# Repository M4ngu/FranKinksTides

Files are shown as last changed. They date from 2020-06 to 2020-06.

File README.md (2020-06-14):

# FranKinksTides
cc-by-sa original     design by Émile Gillet

https://www.tesseractmodular.com/eurorack-modules/frankinkstides-1-2

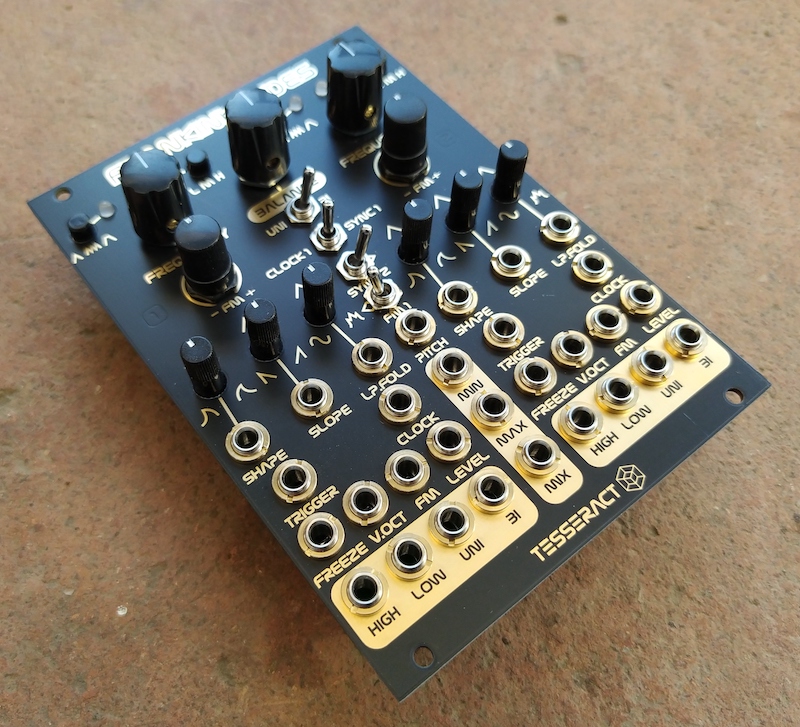
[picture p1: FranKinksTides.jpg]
FranKinksTides


Dual Tidal Modulator - Eurorack Module

FranKinksTides is a eurorack module with 2 tidal modulators based on MI Tides1 (by Émilie Gillet) and the Swirls PCB layout  (by Electric Mist)

https://mutable-instruments.net/modules/tides1/

The central part is a mixer for the 2 signals and the Max/Min circuit from MI Kinks 

https://mutable-instruments.net/modules/kinks/

It can be a dual function generator, a complex oscillator or any other combination of VCO, LFO, ENV

version history:

## first version

-First working version of this kind of 'digital Maths'

## second version (v1.2):

-Mix output is now buffered, no signal bleeding on single outs.

-Mix pot controls also the balance of the signals sent to the max/min circuit.

-Uni/bi switch now also determines the signal sent to FM1.

-Clock/sync switch has now a center OFF position, no need of plugging a dummy cable in the Clock1 when using Sheeps firmware to avoid ultra fast sound bank changes. 

other small improvements for DIY:

-Bigger font size on the pcb.

-Parts renumbered for easy DIY.

## last version (v1.4):

-Added resistors to make the Balance pot exponential, so center position has a louder output.

-PCB modified with the Thonkiccon recommendation (with no ground plane / traces under the jacks)

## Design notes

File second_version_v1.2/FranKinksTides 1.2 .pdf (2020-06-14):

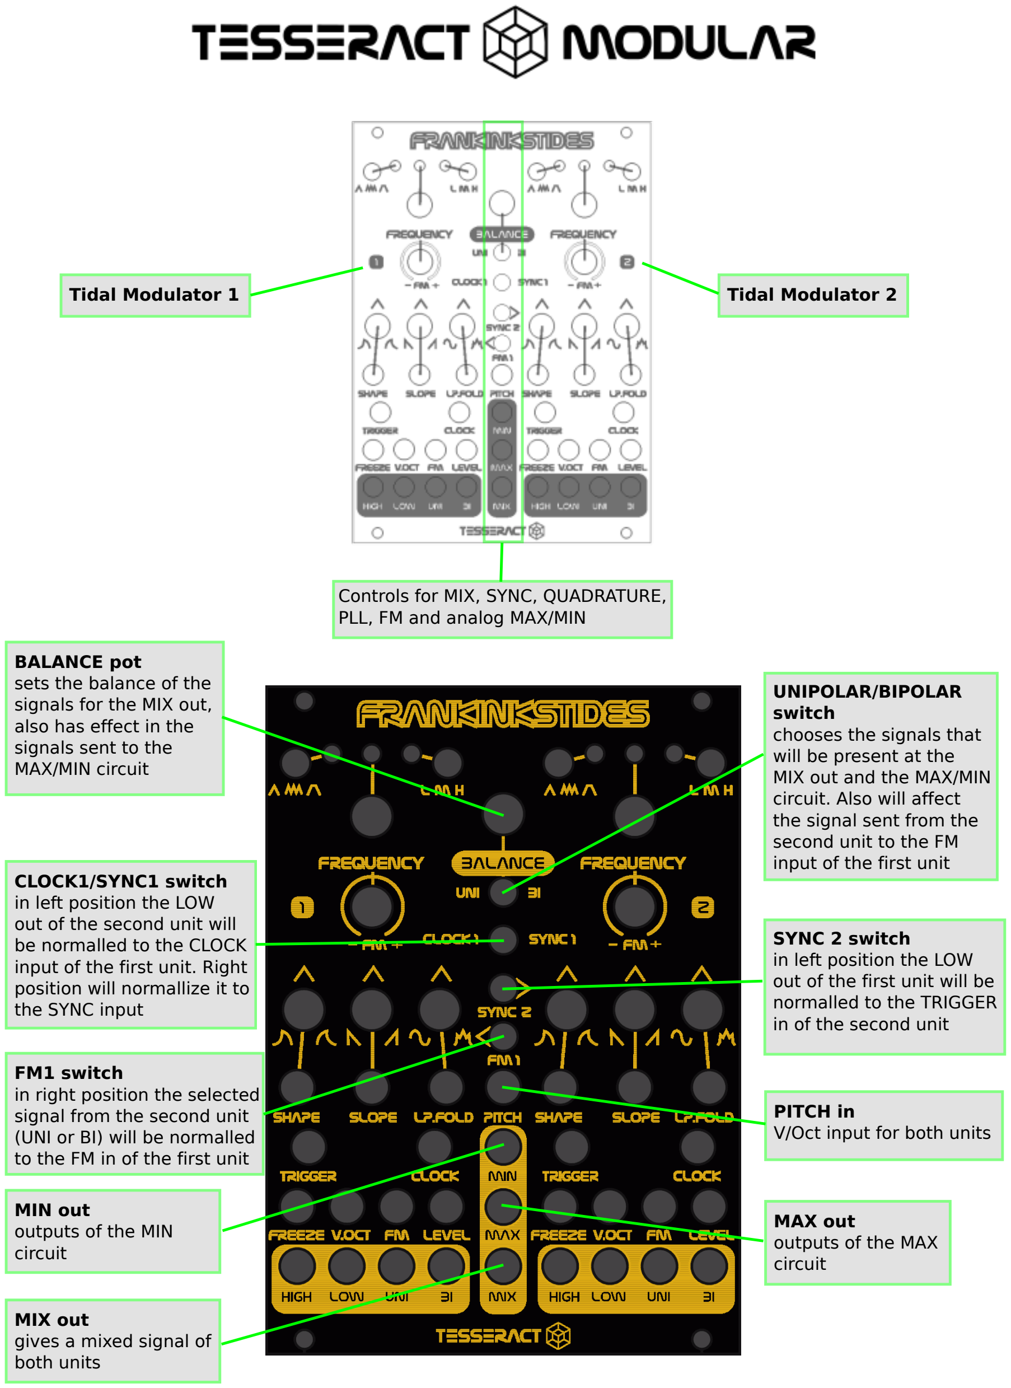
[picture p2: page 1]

BALANCE pot
sets the balance of the
signals for the MIX out,
also has effect in the
signals sent to the
MAX/MIN circuit

UNIPOLAR/BIPOLAR
switch
chooses the signals that
will be present at the
MIX out and the MAX/MIN
circuit. Also will affect
the signal sent from the
second unit to the FM
input of the first unit

MIX out
gives a mixed signal of
both units

MIN out
outputs of the MIN
circuit

SYNC 2 switch
in left position the LOW
out of the first unit will be normalled to the TRIGGER
in of the second unit

CLOCK1/SYNC1 switch
in left position the LOW
out of the second unit will be normalled to the CLOCK
input of the first unit. Right position will normallize it to the SYNC input

MAX out
outputs of the MAX
circuit

PITCH in
V/Oct input for both units

FM1 switch
in right position the selected signal from the second unit (UNI or BI) will be normalled to the FM in of the first unit
Tidal Modulator 1 | Tidal Modulator 2

Controls for MIX, SYNC, QUADRATURE, PLL, FM and analog MAX/MIN

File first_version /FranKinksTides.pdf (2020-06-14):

# FranKinksTides – Tesseract Modular

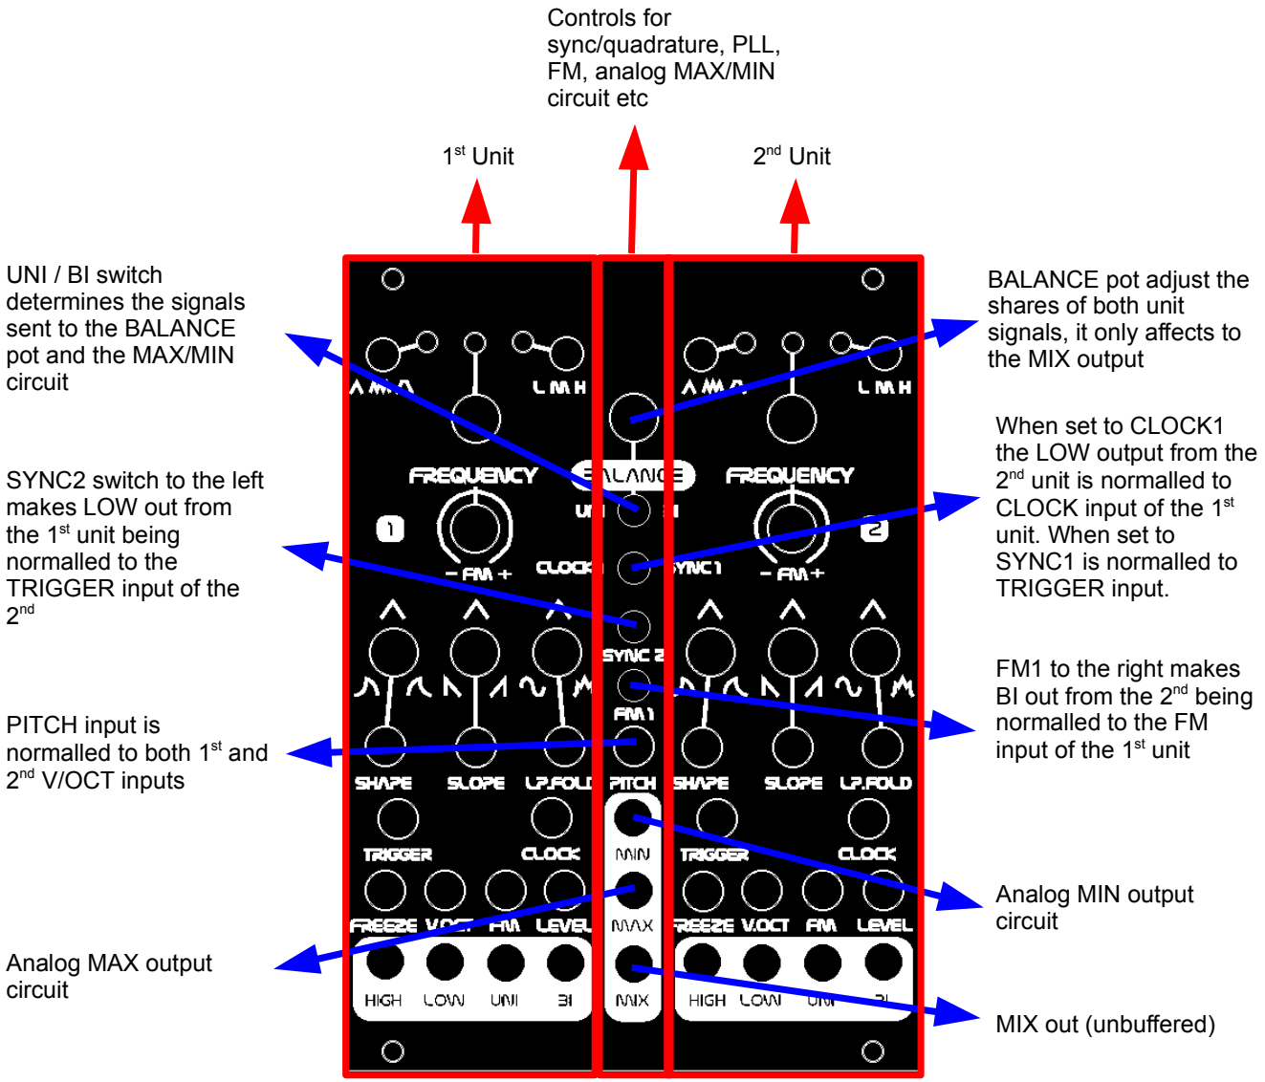
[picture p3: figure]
BALANCE pot adjust the shares of both unit signals, it only affects to the MIX output; UNI / BI switch determines the signals sent to the BALANCE pot and the MAX/MIN circuit; SYNC2 switch to the left makes LOW out from the 1st unit being normalled to the TRIGGER input of the 2; PITCH input is normalled to both 1st and 2; nd V/OCT inputs; FM1 to the right makes BI out from the 2nd being normalled to the FM input of the 1st unit; When set to CLOCK1 the LOW output from the 2; nd unit is normalled to CLOCK input of the 1st unit. When set to SYNC1 is normalled to TRIGGER input.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

B.O.M.:
htps://drive.google.com/open?id=1qt1LPLmPkDN1XobC-u9hoLfQJoos-VuX2zH6MlWJix4

MOUSER CART (without pots, switches and jacks): htps://www.mouser.com/ProjectManager/ProjectDetail.aspx?AccessID=BC3FC77538

Derivatve work from MUTABLE INSTRUMENTS TIDES & KINKS by Olivier Gillet Based on the SWIRLS layout by Electric Mist

cc-by-sa

htps://www.facebook.com/Tesseract-Modular-146727136274298

tesseract.modular@gmail.com

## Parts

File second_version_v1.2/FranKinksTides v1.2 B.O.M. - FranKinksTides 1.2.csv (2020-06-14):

Index | Value | Qty | Description | Specs | Package | Ref. Mouser | References
R120 | 51 | 1 | Resistor, 1% |  | 603 | 603-RC0603FR-0751RL
R3, R4, R5, R6, R7, R8, R9, R10, R11, R12, R13, R14, R71, R74, R94, R95 | 100 | 16 | Resistor, 1% |  | 603 | 652-CR0603FX-1000ELF
R76, R83 | 180 | 2 | Resistor, 1% |  | 603 | 652-CR0603FX-1800ELF
R66, R67 | 270 | 2 | Resistor, 1% |  | 603 | 652-CR0603FX-2700ELF
R20, R21 | 2.49k | 2 | Resistor, 1% |  | 603 | 652-CR0603FX-2491ELF
R88, R89 | 2.49k | 2 | Resistor, 1% |  | 805 | 652-CR0805FX-2491ELF
R64, R65, R103, R106, R112, R115 | 3.3k | 6 | Resistor, 1% |  | 603 | 652-CR0603-FX3301ELF
R104, R105, R113, R114 | 4.7k | 4 | Resistor, 1% |  | 603 | 652-CR0603FX-4701ELF
R96, R97, R98, R99, R100, R101, R102, R107, R111, R116 | 10k | 10 | Resistor, 1% |  | 603 | 652-CR0603-FX-1002GLF
R52, R53 | 20k | 2 | Resistor, 1% |  | 603 | 652-CR0603FX-2002ELF
R28, R31 | 27k | 2 | Resistor, 1% |  | 603 | 652-CR0603FX-2702ELF
R77, R78 | 30k | 2 | Resistor, 1% |  | 603 | 652-CR0603FX-3002ELF
R39, R41, R42, R43, R44, R45, R84, R85, R86, R87 | 33k | 10 | Resistor, 1% |  | 603 | 652-CR0603FX-3302ELF
R48, R51 | 39k | 2 | Resistor, 1% |  | 603 | 652-CR0603FX-3902ELF
R17, R18, R19, R22, R23, R26, R27, R29, R30, R32, R33, R34, R35, R36, R37, R38, R40, R47, R50, R58, R59, R60, R61, R62, R63, R79, R80, R81, R82, R91, R93, R108, R109, R110, R117, R118, R119 | 100k | 37 | Resistor, 1% |  | 603 | 652-CR0603-FX-1003GLF
R24, R25, | 100k | 2 | Resistor 1% |  | 603 | 652-CR0603-FX-1003GLF | pulldown resistors, other values possible
R54, R55, R56, R57, R70, R73 | 120k | 6 | Resistor, 1% |  | 603 | 652-CR0603FX-1203ELF
R1, R2, R15, R16, R72, R75, R90, R92 | 220k | 8 | Resistor, 1% |  | 603 | 652-CR0603FX-2203ELF
R46, R49 | 3.3M | 2 | Resistor, 1% |  | 603 | 71-CRCW06033M30FKEA
C20 | 10p | 1 | Capacitor, ceramic | >= 16V, <= 5%, C0G | 603 | 81-GCM1885C2A100JA6J
C10, C11, C12, C13 | 18p | 4 | Capacitor, ceramic |  | 603 | 81-GRM185C1H180JA01J
C58, C60, C62, C63, C64, C65, C70, C71 | 220p | 8 | Capacitor, ceramic | >= 16V, <= 2%, C0G | 603 | 81-GRM185C1H221GA01D
C30, C31, C41, C43, C46, C47 | 1n | 6 | Capacitor, ceramic | >= 50V, <= 2%, C0G | 603 | 81-GRM1885C1H102FA1J
C32, C33, C34, C35, C40, C42 | 10n | 6 | Capacitor, ceramic | >= 50V, <= 5% | 603 | 81-GCM188R71H103JA7D
C1, C2, C3, C4, C14, C15, C16, C21, C22, C23, C24, C25, C26, C27, C36, C37, C38, C39, C44, C45, C48, C49, C56, C57, C59, C61, C66, C67, C68, C69 | 100n | 30 | Capacitor, ceramic | >= 16V | 603 | 80-C0603C104K4R7411
C52, C53, C54, C55 | 470n | 4 | Capacitor, ceramic | >= 16V | 603 | 581-0603YG474Z
C28, C29, C50, C51 | 3.3u | 4 | Capacitor, ceramic | >= 6.3V | 603 | 81-GCJ188C70J335KE2D
C6, C7, C8, C9, C17, C18 | 22u | 6 | Capacitor, electrolytic | >= 25V | Panasonic C | 667-EEE-FP1E220AR | EEE-FP1E220AR
C5, C19 | 47u | 2 | Capacitor, electrolytic | >= 25V | Panasonic D | 667-EEE-FK1V470P | EEEFK1V470P
D4, D8 |  | 2 | 1N5819HW diode |  | SOD123 | 621-1N5819HW-F | Diodes Inc 1N5819HW-7-F
D1, D2, D3, D5, D6, D7 |  | 6 | 1N4148 |  | SOD123 | 621-1N4148W-F
IC1, IC2, IC3, IC4 | 3.3V | 4 | LM1117-3.3V LDO Vreg |  | SO223 | 926-LM1117MPX3.3NOPB | National LM1117MPX3.3NOPB
IC11, IC12 | 2.5V | 2 | LM4040 Shunt Vref | A, B or C grade | SOT23 | 595-LM4040C25IDBZR | Texas Instruments LM4040C25IDBZ
IC13, IC14 | 10V | 2 | LM4040 Shunt Vref | A, B or C grade | SOT23 | 595-LM4040C10IDBZR | Texas Instruments LM4040C10IDBZ
IC9, IC10 |  | 2 | DAC8552 dual 16-bit DAC |  | MSOP8 | 595-DAC8552IDGKT | Texas Instruments DAC8552IDGKT
IC15, IC16, IC17, IC18, U1, U2 |  | 6 | TL072 dual op-amp |  | TSSOP-8 | 595-TL072CPWR | TI TL072CPWR
IC7, IC8 |  | 2 | MCP6002 dual op-amp R2R IO |  | SOIC8 | 579-MCP6002-I/SN | MCP6002-I/SN
IC5, IC6 |  | 2 | MCP6004 dual op-amp R2R IO |  | TSSOP-14 | 579-MCP6004-I/ST | MCP6004-I/ST
Q3, Q4, Q5, Q6, Q7, Q8, Q9, Q10, Q11, Q12 |  | 10 | NPN transistor MMBT3904 |  | SOT23 | 863-MMBT3904LT1G | On Semi MMBT3904LT1G
Q1, Q2 |  | 2 | 8 MHz quartz |  | HC49 | 815-ABLS2-8-D4Y-T | Abracon ABLS2-8.000MHZ-D4Y-T
UC1, UC2 |  | 2 | STM32F103CBT6 MCU |  | LQFP48 | 511-STM32F103CBT6 | ST STM32F103CBT6
TH parts
J1, J2, J3, J4, J5, J6, J7, J8, J9, J10, J11, J12, J13, J14, J15, J16, J17, J18, J19, J20, J21, J22, J23, J24, J25, J26, J30, MAX, MIN, MIX |  | 30 | Vertical jack connector |  |  | PJ-301-M-12 | https://www.thonk.co.uk/shop/3-5mm-jacks/
LED1, LED2, LED3, LED4, LED5, LED6 |  | 6 | LED, Red/Green, 3 terminals, common K |  | 3 terminals | 604-WP115VEGW | Kingbright WP115VEGW
SW1, SW2, SW3, SW4 |  | 4 | Push-button 6.0X2.8MM |  |  | 612-TL1105SP-250 | E-switch TL1105SPF250Q
 |  | 4 | Push-button caps |  |  | 612-1R-BK | E-switch 1RBLK
VR1 | 20-100k | 1 | ALPHA-9MM-DUALPOT | linear |  |  | https://www.thonk.co.uk/shop/alpha-9mm-pots-vertical-t18/
R121, R122 |  | 2 | 10k linear pot, 15mm shaft |  |  |  | https://www.thonk.co.uk/shop/alpha-9mm-pots-vertical-t18/
R123, R124, R125, R126, R127, R128, R129, R130 |  | 8 | 10k linear Tall Trimmer |  |  |  | https://www.thonk.co.uk/shop/ttpots/
R68, R69 | 50k | 2 | 50k Trimmer resistor, 25 turns, top adjust. |  |  | 652-3296W-1-503LF | 3296W-1-503LF
POWER |  | 1 | 2x5 male header, 2.54mm pitch |  |  | 649-67996-410HLF
JTAG, JTAG1 |  | 2 | 2x5, 1.27mm pitch male header |  |  | 649-221111-00010T4LF
UNI-BI |  | 1 | Sub-miniature ON-ON | DPDT |  | 108-2MD1T1B1M2QE-EVX | https://www.thonk.co.uk/shop/sub-mini-toggle-switches/
SYNC-A |  | 1 | Sub-miniature ON-OFF-ON | SPDT |  | 108-2MS3T1B1M2QE-EVX
FM-A, SYNC-B |  | 2 | Sub-miniature ON-ON | SPDT |  | 108-2MS1T1B1M2QE-EVX | https://www.thonk.co.uk/shop/sub-mini-toggle-switches/
MOUSER CART (without pots and jacks) | https://www.mouser.com/ProjectManager/ProjectDetail.aspx?AccessID=9fbd7b471f

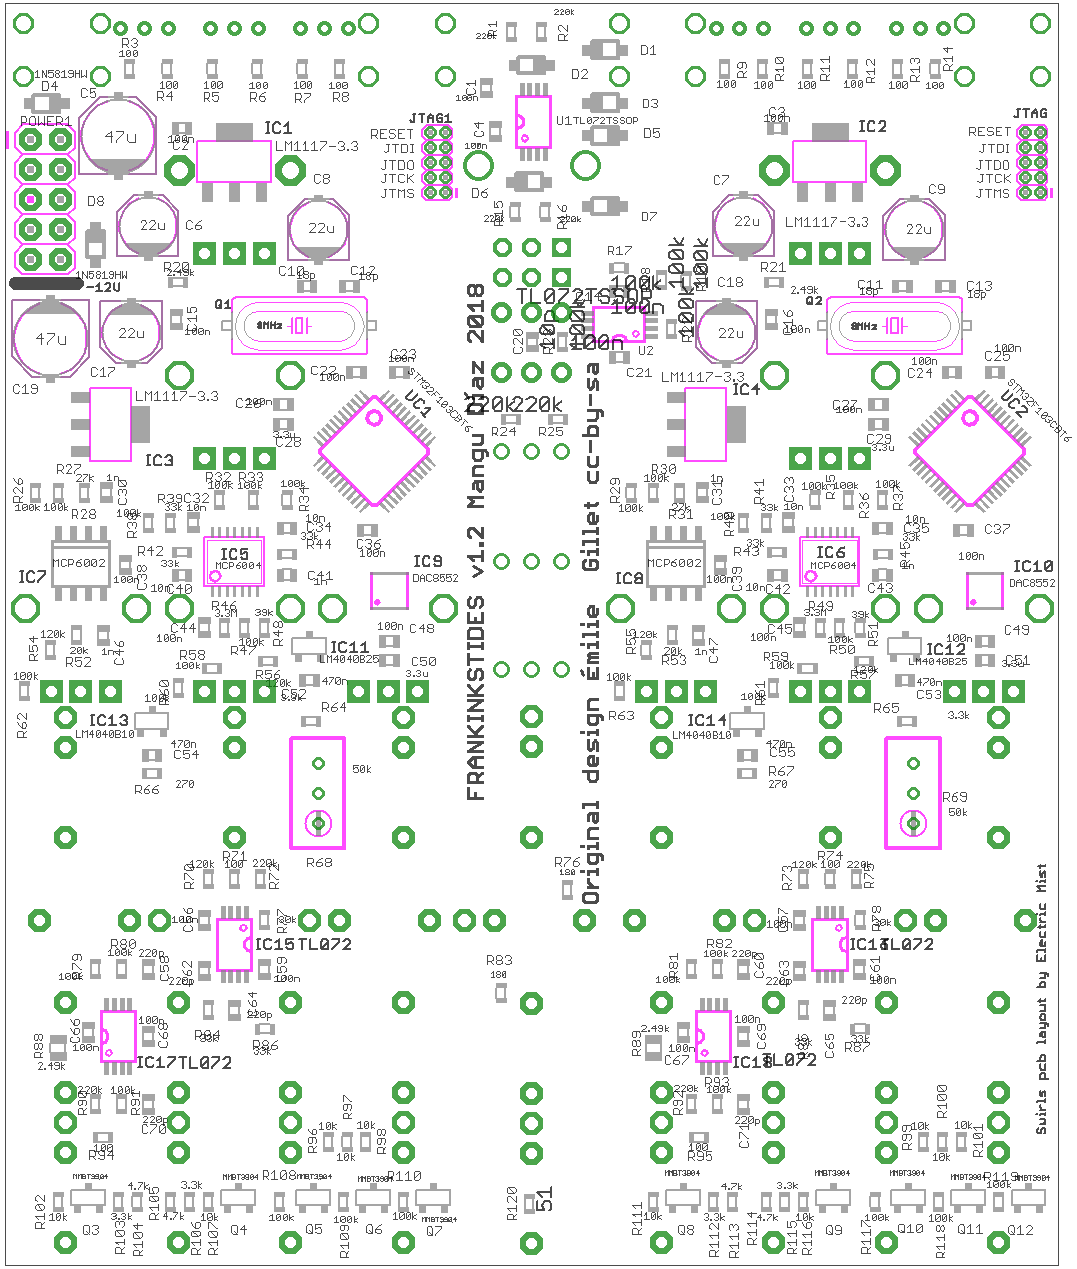
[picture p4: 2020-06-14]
second_version_v1.2/ComponentMap.png

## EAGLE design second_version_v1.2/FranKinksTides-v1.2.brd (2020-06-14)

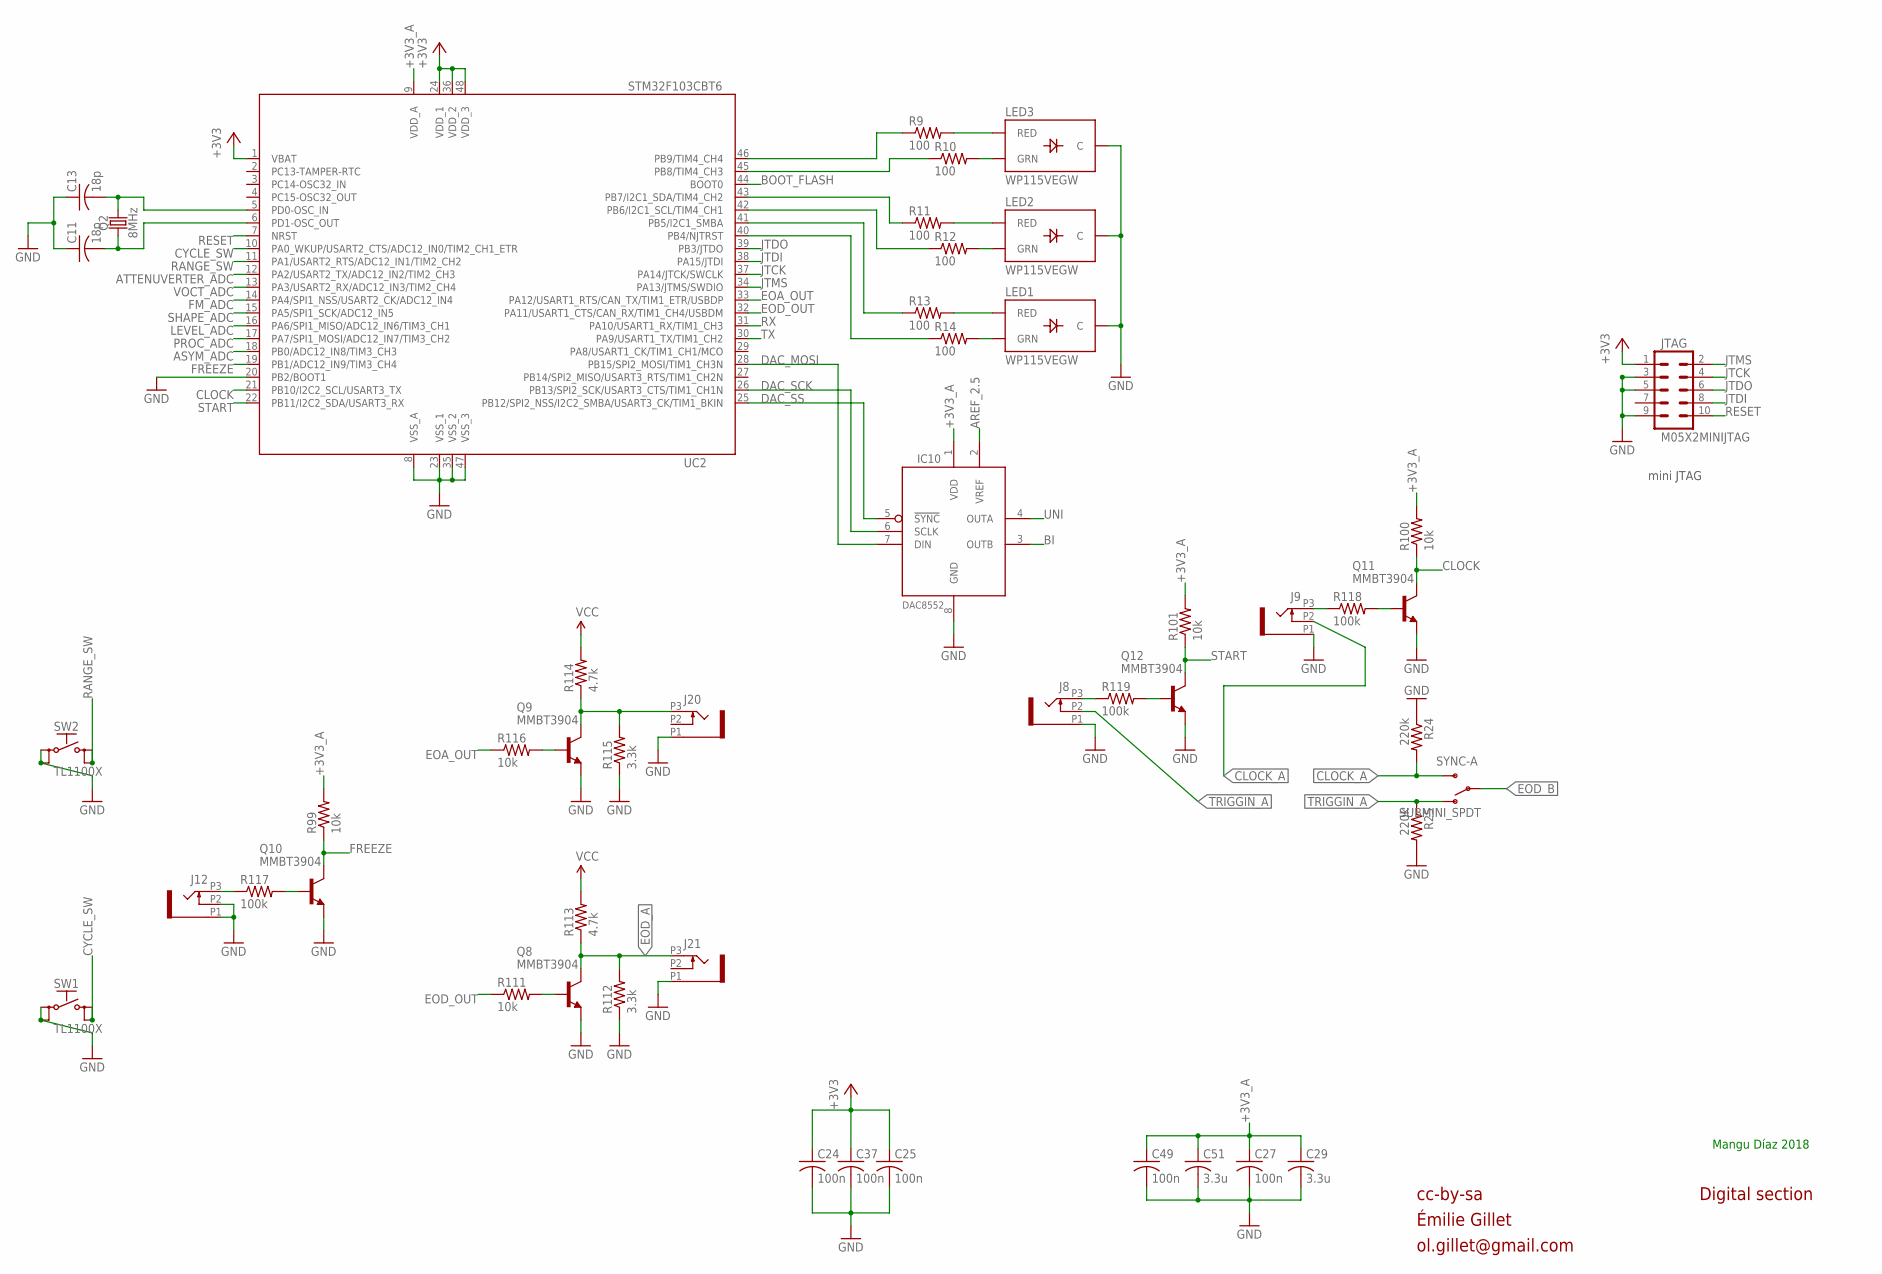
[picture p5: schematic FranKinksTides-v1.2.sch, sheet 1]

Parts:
C11, C13: 18p; C0603
C24, C25, C27, C37, C49: 100n; C0603
C29, C51: 3.3u; C0603
IC10: DAC8552; MSOP-8
J8, J9, J12, J20, J21: PJ301_GUI6; OG-PJ301_VARIATIONS_WQP_PJ_301M6
JTAG: M05X2MINIJTAG; 2X5-1.27
LED1, LED2, LED3: WP115VEGW; LED-BICOLOR-THROUGHHOLE
Q2: 8MHz; HC49UP
Q8, Q9, Q10, Q11, Q12: MMBT3904; SOT23-BEC
R9, R10, R11, R12, R13, R14: 100; R0603
R24, R25: 220k; R0603
R99, R100, R101, R111, R116: 10k; R0603
R112, R115: 3.3k; R0603
R113, R114: 4.7k; R0603
R117, R118, R119: 100k; R0603
SW1, SW2: TL1100X
SYNC-A: SUBMINI_SPDT; SUBMINI_TOGGLE
UC2: STM32F103CBT6; LQFP48

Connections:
+3V3: C24.1, C25.1, C37.1, JTAG.1, UC2.1 (VBAT), UC2.24 (VDD_1), UC2.36 (VDD_2), UC2.48 (VDD_3); also elsewhere on the board
+3V3_A: C27.1, C29.1, C49.1, C51.1, IC10.1 (VDD), R99.2, R100.2, R101.2, UC2.9 (VDD_A); also elsewhere on the board
AREF_2.5: IC10.2 (VREF); also elsewhere on the board
ASYM_ADC: UC2.18 (PB0/ADC12_IN8/TIM3_CH3); also elsewhere on the board
ATTENUVERTER_ADC: UC2.12 (PA2/USART2_TX/ADC12_IN2/TIM2_CH3); also elsewhere on the board
BI: IC10.3 (OUTB); also elsewhere on the board
BOOT_FLASH: UC2.44 (BOOT0); also elsewhere on the board
CLOCK: Q11.C, R100.1, UC2.21 (PB10/I2C2_SCL/USART3_TX); also elsewhere on the board
CLOCK_A: J9.P2 (2), R24.2, SYNC-A.3 (S)
CYCLE_SW: SW1.3 (S), SW1.4 (S1), UC2.10 (PA0_WKUP/USART2_CTS/ADC12_IN0/TIM2_CH1_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); also elsewhere on the board
DAC_MOSI: IC10.7 (DIN), UC2.28 (PB15/SPI2_MOSI/TIM1_CH3N); also elsewhere on the board
DAC_SCK: IC10.6 (SCLK), UC2.26 (PB13/SPI2_SCK/USART3_CTS/TIM1_CH1N); also elsewhere on the board
DAC_SS: IC10.5 (!SYNC), UC2.25 (PB12/SPI2_NSS/I2C2_SMBA/USART3_CK/TIM1_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); also elsewhere on the board
EOA_OUT: R116.1, UC2.33 (PA12/USART1_RTS/CAN_TX/TIM1_ETR/USBDP); also elsewhere on the board
EOD_A: J21.P3 (3), Q8.C, R112.2, R113.1; also elsewhere on the board
EOD_B: SYNC-A.COM (COMMON); also elsewhere on the board
EOD_OUT: R111.1, UC2.32 (PA11/USART1_CTS/CAN_RX/TIM1_CH4/USBDM); also elsewhere on the board
FM_ADC: UC2.14 (PA4/SPI1_NSS/USART2_CK/ADC12_IN4); also elsewhere on the board
FREEZE: Q10.C, R99.1, UC2.19 (PB1/ADC12_IN9/TIM3_CH4); also elsewhere on the board
GND: C11.1, C13.1, C24.2, C25.2, C27.2, C29.2, C37.2, C49.2, C51.2, IC10.8 (GND), J8.P1 (1), J9.P1 (1), J12.P1 (1), J12.P2 (2), J20.P1 (1), J21.P1 (1), JTAG.3, JTAG.5, JTAG.9, LED1.2 (C), LED2.2 (C), LED3.2 (C), Q8.E, Q9.E, Q10.E, Q11.E, Q12.E, R24.1, R25.2, R112.1, R115.1, SW1.1, SW1.2 (P1), SW2.1, SW2.2 (P1), UC2.8 (VSS_A), UC2.20 (PB2/BOOT1), UC2.23 (VSS_1), UC2.35 (VSS_2), UC2.47 (VSS_3); also elsewhere on the board
JTCK: JTAG.4, UC2.37 (PA14/JTCK/SWCLK); also elsewhere on the board
JTDI: JTAG.8, UC2.38 (PA15/JTDI); also elsewhere on the board
JTDO: JTAG.6, UC2.39 (PB3/JTDO); also elsewhere on the board
JTMS: JTAG.2, UC2.34 (PA13/JTMS/SWDIO); also elsewhere on the board
LEVEL_ADC: UC2.16 (PA6/SPI1_MISO/ADC12_IN6/TIM3_CH1); also elsewhere on the board
unnamed: C13.2, Q2.2, UC2.5 (PD0-OSC_IN)
unnamed: C11.2, Q2.1, UC2.6 (PD1-OSC_OUT)
unnamed: J8.P3 (3), R119.1
unnamed: J12.P3 (3), R117.1
unnamed: Q10.B, R117.2
unnamed: J9.P3 (3), R118.1
unnamed: Q11.B, R118.2
unnamed: Q8.B, R111.2
unnamed: LED3.3 (RED), R9.2
unnamed: LED3.1 (GRN), R10.2
unnamed: LED2.3 (RED), R11.2
unnamed: LED2.1 (GRN), R12.2
unnamed: LED1.3 (RED), R13.2
unnamed: LED1.1 (GRN), R14.2
unnamed: R9.1, UC2.46 (PB9/TIM4_CH4)
unnamed: R10.1, UC2.45 (PB8/TIM4_CH3)
unnamed: R11.1, UC2.43 (PB7/I2C1_SDA/TIM4_CH2)
unnamed: R12.1, UC2.42 (PB6/I2C1_SCL/TIM4_CH1)
unnamed: R13.1, UC2.41 (PB5/I2C1_SMBA)
unnamed: R14.1, UC2.40 (PB4/NJTRST)
unnamed: J20.P3 (3), Q9.C, R114.1, R115.2
unnamed: Q9.B, R116.2
unnamed: Q12.B, R119.2
PROC_ADC: UC2.17 (PA7/SPI1_MOSI/ADC12_IN7/TIM3_CH2); also elsewhere on the board
RANGE_SW: SW2.3 (S), SW2.4 (S1), UC2.11 (PA1/USART2_RTS/ADC12_IN1/TIM2_CH2); also elsewhere on the board
RESET: JTAG.10, UC2.7 (NRST); also elsewhere on the board
RX: UC2.31 (PA10/USART1_RX/TIM1_CH3); also elsewhere on the board
SHAPE_ADC: UC2.15 (PA5/SPI1_SCK/ADC12_IN5); also elsewhere on the board
START: Q12.C, R101.1, UC2.22 (PB11/I2C2_SDA/USART3_RX); also elsewhere on the board
TRIGGIN_A: J8.P2 (2), R25.1, SYNC-A.1 (O)
TX: UC2.30 (PA9/USART1_TX/TIM1_CH2); also elsewhere on the board
UNI: IC10.4 (OUTA); also elsewhere on the board
VCC: R113.2, R114.2; also elsewhere on the board
VOCT_ADC: UC2.13 (PA3/USART2_RX/ADC12_IN3/TIM2_CH4); also elsewhere on the board

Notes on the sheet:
cc-by-sa
Émilie Gillet
ol.gillet@gmail.com
Digital section
mini JTAG
Mangu Díaz 2018

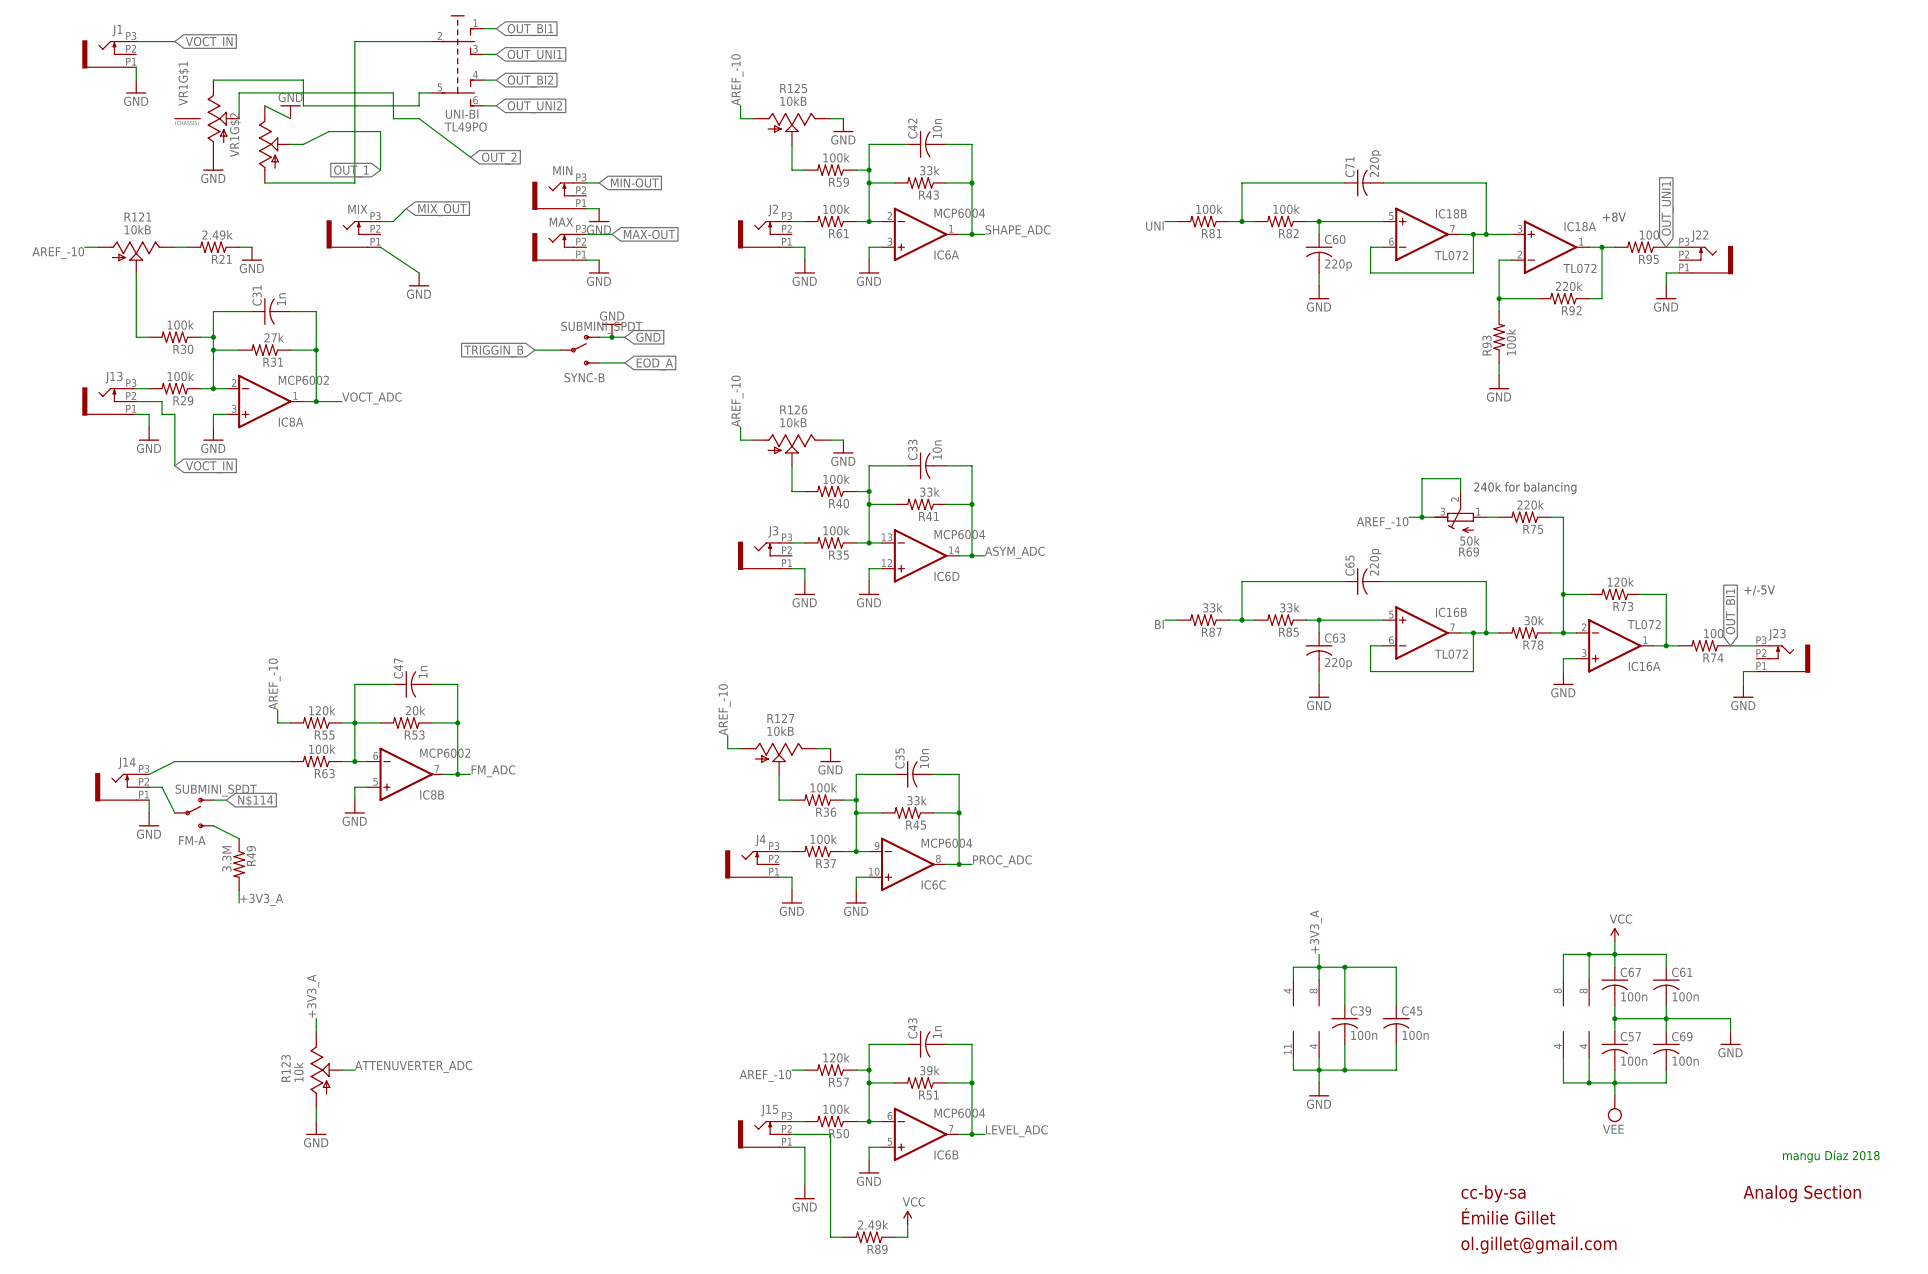
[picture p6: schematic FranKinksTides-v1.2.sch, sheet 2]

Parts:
C31, C43, C47: 1n; C0603
C33, C35, C42: 10n; C0603
C39, C45, C57, C61, C67, C69: 100n; C0603
C60, C63, C65, C71: 220p; C0603
FM-A: SUBMINI_SPDT; SUBMINI_TOGGLE
IC6: MCP6004; TSSOP14
IC8: MCP6002; SO08
IC16, IC18: TL072; TSSOP-8
J1, J2, J3, J4, J13, J14, J15, J22, J23: PJ301_GUI6; OG-PJ301_VARIATIONS_WQP_PJ_301M6
MAX: PJ301_GUI6; OG-PJ301_VARIATIONS_WQP_PJ_301M6
MIN: PJ301_GUI6; OG-PJ301_VARIATIONS_WQP_PJ_301M6
MIX: PJ301_GUI6; OG-PJ301_VARIATIONS_WQP_PJ_301M6
R21: 2.49k; R0603
R29, R30, R35, R36, R37, R40, R50, R59, R61, R63, R81, R82, R93: 100k; R0603
R31: 27k; R0603
R41, R43, R45, R85, R87: 33k; R0603
R49: 3.3M; R0603
R51: 39k; R0603
R53: 20k; R0603
R55, R57, R73: 120k; R0603
R69: 50k; RTRIM3296W
R74, R95: 100; R0603
R75, R92: 220k; R0603
R78: 30k; R0603
R89: 2.49k; R0805
R121: 10kB; ALPS_POT_VERTICAL_PS
R123: 10k; TALLTRIMMER
R125, R126, R127: 10kB; TALLTRIMMER
SYNC-B: SUBMINI_SPDT; SUBMINI_TOGGLE
UNI-BI: TL49PO; TL4XPO
VR1: ALPHA-9MM-DUALPOT; DUAL_9MM_SNAP-IN_POT

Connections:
+3V3_A: C39.1, C45.1, IC6.4 (V+), IC8.8 (V+), R49.2, R123.P$1 (E); also elsewhere on the board
AREF_-10: R55.2, R57.2, R69.2 (S), R69.3 (E), R121.P$3 (A), R125.P$3 (A), R126.P$3 (A), R127.P$3 (A); also elsewhere on the board
ASYM_ADC: C33.2, IC6.14 (OUT), R41.1; also elsewhere on the board
ATTENUVERTER_ADC: R123.P$2 (S); also elsewhere on the board
BI: R87.2; also elsewhere on the board
BI_OUT: IC16.1 (OUT), R73.1, R74.2
EOD_A: SYNC-B.3 (S); also elsewhere on the board
FM_ADC: C47.2, IC8.7 (OUT), R53.1; also elsewhere on the board
F_CV: IC16.2 (-IN), R73.2, R75.1, R78.1
GND: C39.2, C45.2, C57.1, C60.2, C61.2, C63.2, C67.2, C69.1, IC6.3 (+IN), IC6.5 (+IN), IC6.10 (+IN), IC6.11 (V-), IC6.12 (+IN), IC8.3 (+IN), IC8.4 (V-), IC8.5 (+IN), IC16.3 (+IN), J1.P1 (1), J2.P1 (1), J3.P1 (1), J4.P1 (1), J13.P1 (1), J14.P1 (1), J15.P1 (1), J22.P1 (1), J23.P1 (1), MAX.P1 (1), MIN.P1 (1), MIX.P1 (1), R21.1, R93.1, R123.P$3 (A), R125.P$1 (E), R126.P$1 (E), R127.P$1 (E), SYNC-B.1 (O), VR1.1 (A), VR1.3B (E); also elsewhere on the board
LEVEL_ADC: C43.2, IC6.7 (OUT), R51.1; also elsewhere on the board
MAX-OUT: MAX.P3 (3); also elsewhere on the board
MIN-OUT: MIN.P3 (3); also elsewhere on the board
MIX_OUT: MIX.P3 (3); also elsewhere on the board
unnamed: J2.P3 (3), R61.2
unnamed: C42.1, IC6.2 (-IN), R43.2, R59.1, R61.1
unnamed: R59.2, R125.P$2 (S)
unnamed: J3.P3 (3), R35.2
unnamed: C33.1, IC6.13 (-IN), R35.1, R40.1, R41.2
unnamed: FM-A.3 (S), R49.1
unnamed: R40.2, R126.P$2 (S)
unnamed: J4.P3 (3), R37.2
unnamed: C35.1, IC6.9 (-IN), R36.1, R37.1, R45.2
unnamed: R36.2, R127.P$2 (S)
unnamed: J15.P3 (3), R50.2
unnamed: C43.1, IC6.6 (-IN), R50.1, R51.2, R57.1
unnamed: J13.P3 (3), R29.2
unnamed: C31.1, IC8.2 (-IN), R29.1, R30.1, R31.2
unnamed: R30.2, R121.P$2 (S)
unnamed: R21.2, R121.P$1 (E)
unnamed: J14.P3 (3), R63.2
unnamed: C47.1, IC8.6 (-IN), R53.2, R55.1, R63.1
unnamed: FM-A.COM (COMMON), J14.P2 (2)
unnamed: R69.1 (A), R75.2
unnamed: IC18.2 (-IN), R92.2, R93.2
unnamed: C65.2, IC16.6 (-IN), IC16.7 (OUT), R78.2
unnamed: C63.1, IC16.5 (+IN), R85.1
unnamed: C65.1, R85.2, R87.1
unnamed: IC18.1 (OUT), R92.1, R95.2
unnamed: J15.P2 (2), R89.2
unnamed: C71.2, IC18.3 (+IN), IC18.6 (-IN), IC18.7 (OUT)
unnamed: C60.1, IC18.5 (+IN), R82.1
unnamed: C71.1, R81.1, R82.2
unnamed: FM-A.1 (O), UNI-BI.5 (P1), VR1.3 (E)
unnamed: UNI-BI.2, VR1.1B (A)
OUT_1: VR1.2B (S); also elsewhere on the board
OUT_2: VR1.2 (S); also elsewhere on the board
OUT_BI1: J23.P3 (3), R74.1, UNI-BI.1 (O)
OUT_BI2: UNI-BI.4 (O1); also elsewhere on the board
OUT_UNI1: J22.P3 (3), R95.1, UNI-BI.3 (S)
OUT_UNI2: UNI-BI.6 (S1); also elsewhere on the board
PROC_ADC: C35.2, IC6.8 (OUT), R45.1; also elsewhere on the board
SHAPE_ADC: C42.2, IC6.1 (OUT), R43.1; also elsewhere on the board
TRIGGIN_B: SYNC-B.COM (COMMON); also elsewhere on the board
UNI: R81.2; also elsewhere on the board
VCC: C61.1, C67.1, IC16.8 (V+), IC18.8 (V+), R89.1; also elsewhere on the board
VEE: C57.2, C69.2, IC16.4 (V-), IC18.4 (V-); also elsewhere on the board
VOCT_ADC: C31.2, IC8.1 (OUT), R31.1; also elsewhere on the board
VOCT_IN: J1.P3 (3), J13.P2 (2); also elsewhere on the board

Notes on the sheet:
cc-by-sa
Émilie Gillet
ol.gillet@gmail.com
Analog Section
+8V
+/-5V
240k for balancing
mangu Díaz 2018

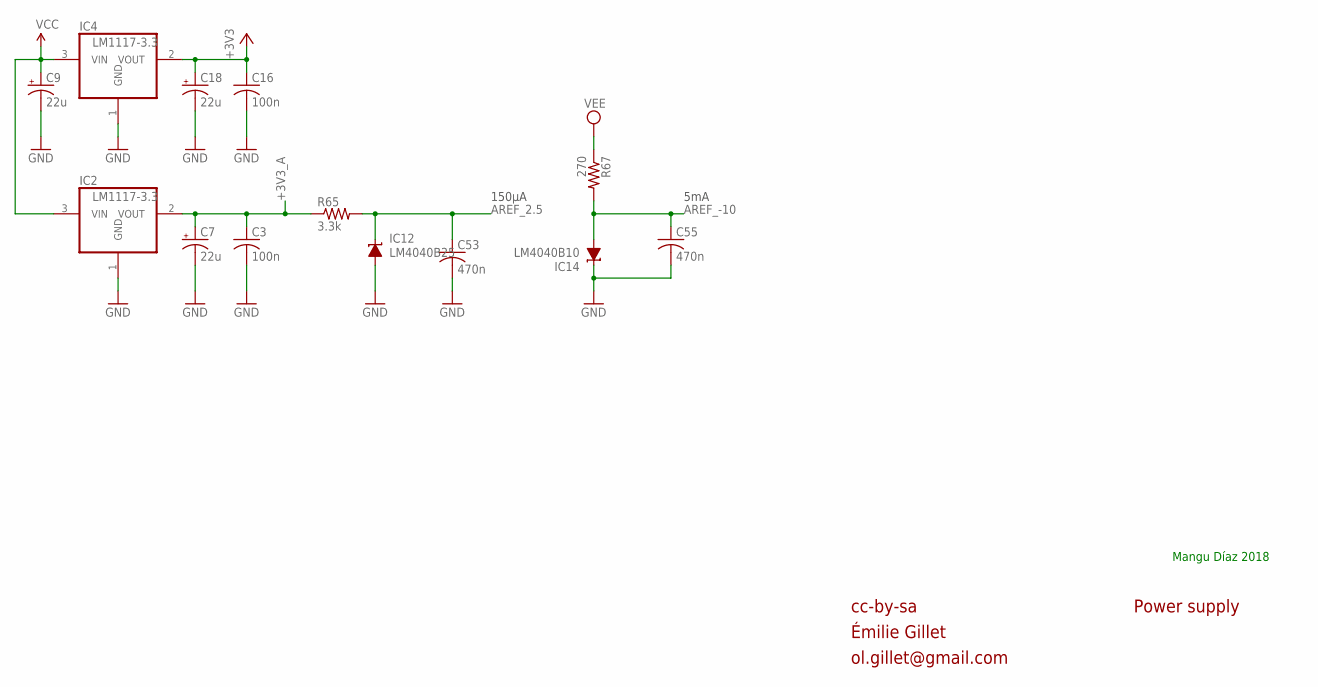
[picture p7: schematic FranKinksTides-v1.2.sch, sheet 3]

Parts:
C3, C16: 100n; C0603
C7, C9, C18: 22u; PANASONIC_C
C53, C55: 470n; C0603
IC2, IC4: LM1117-3.3; SOT223
IC12: LM4040B25; DBZ_R-PDSO-G3
IC14: LM4040B10; DBZ_R-PDSO-G3
R65: 3.3k; R0603
R67: 270; R0603

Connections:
+3V3: C16.1, C18.+, IC4.2 (VOUT); also elsewhere on the board
+3V3_A: C3.1, C7.+, IC2.2 (VOUT), R65.1; also elsewhere on the board
AREF_2.5: C53.1, IC12.1 (C), R65.2; also elsewhere on the board
AREF_-10: C55.1, IC14.2 (A), R67.2; also elsewhere on the board
GND: C3.2, C7.-, C9.-, C16.2, C18.-, C53.2, C55.2, IC2.1 (GND), IC4.1 (GND), IC12.2 (A), IC14.1 (C); also elsewhere on the board
VCC: C9.+, IC2.3 (VIN), IC4.3 (VIN); also elsewhere on the board
VEE: R67.1; also elsewhere on the board

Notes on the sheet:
cc-by-sa
Émilie Gillet
ol.gillet@gmail.com
Power supply
5mA
150µA
Mangu Díaz 2018

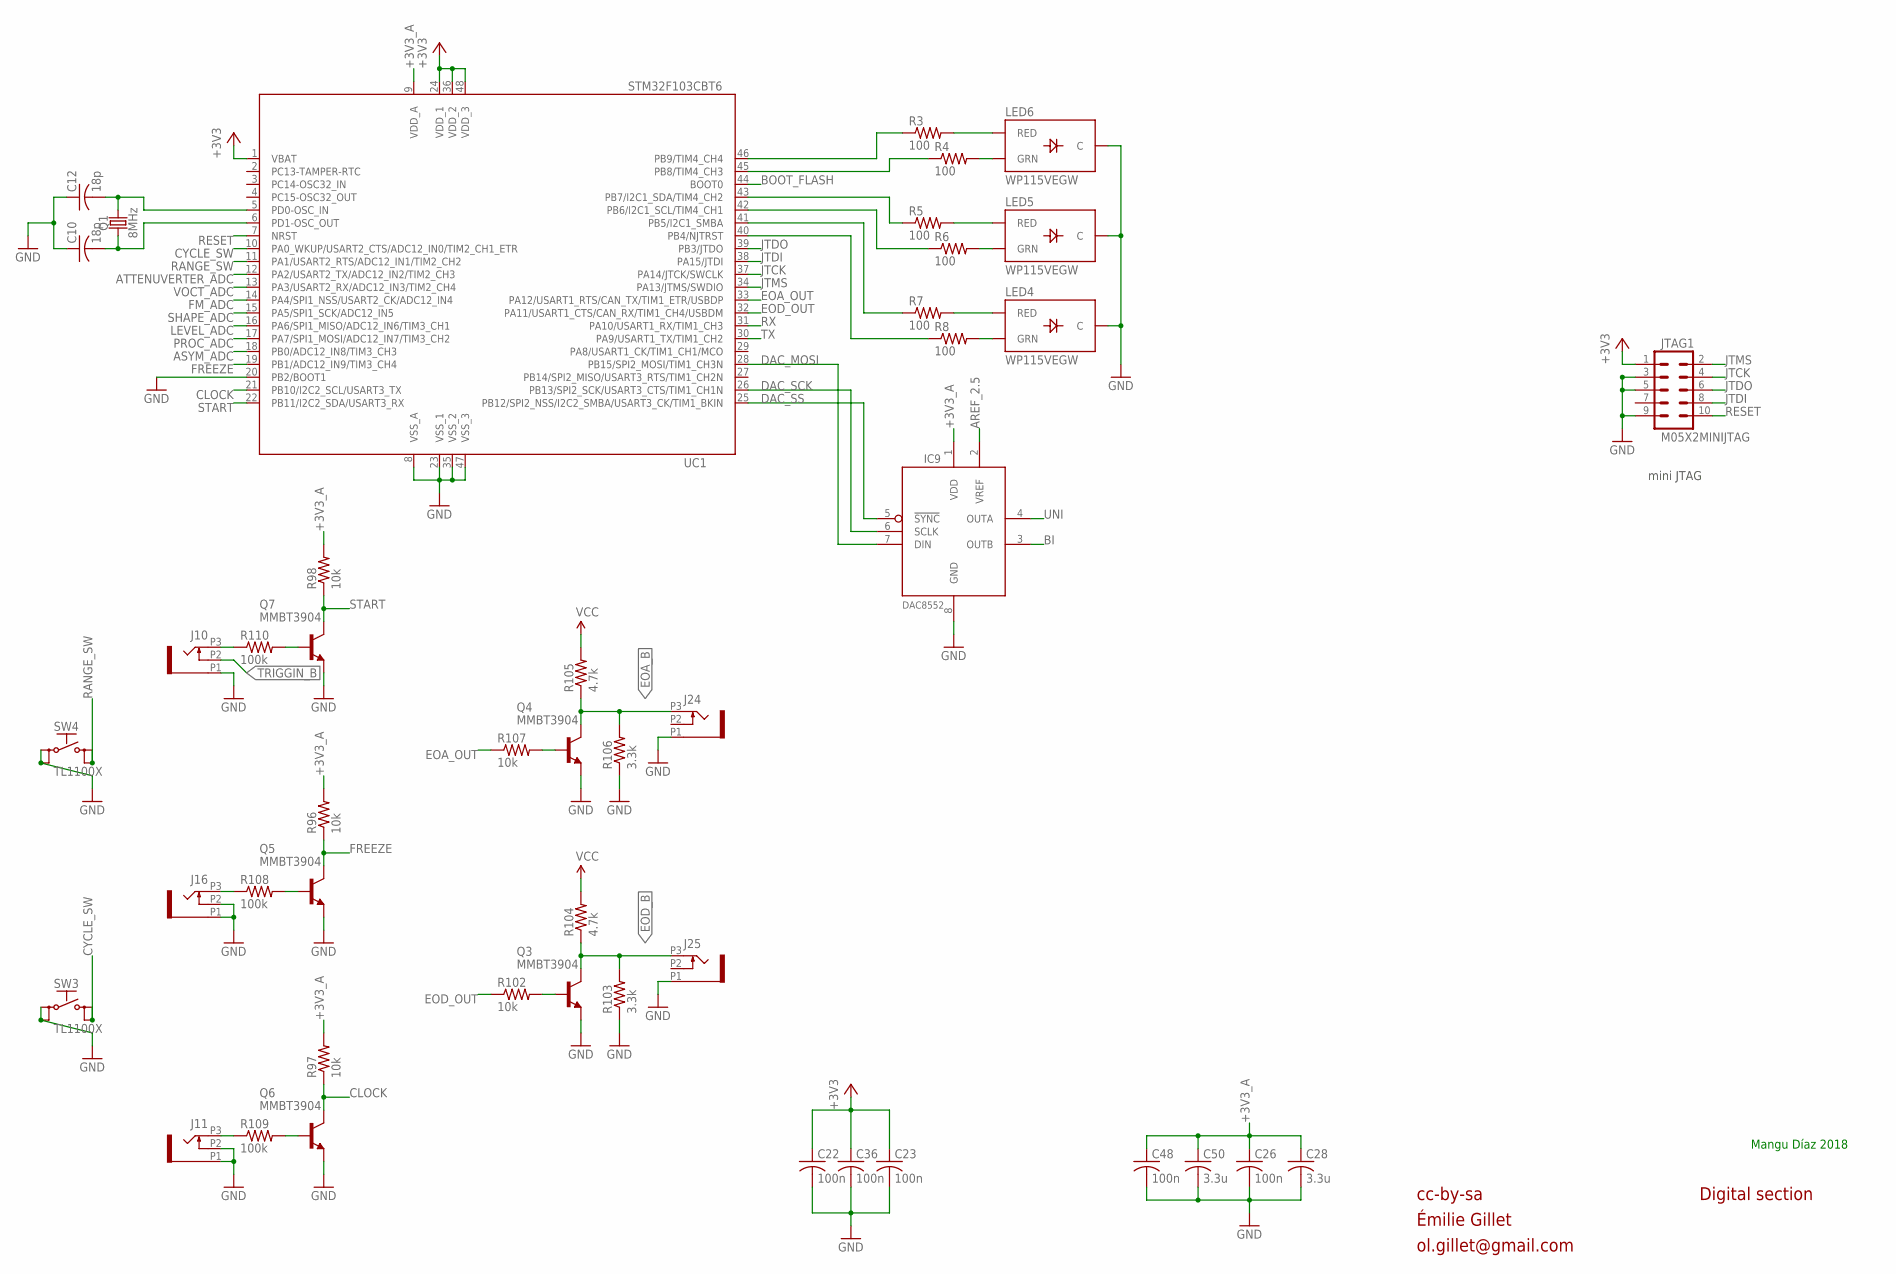
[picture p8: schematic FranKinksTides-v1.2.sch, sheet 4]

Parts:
C10, C12: 18p; C0603
C22, C23, C26, C36, C48: 100n; C0603
C28, C50: 3.3u; C0603
IC9: DAC8552; MSOP-8
J10, J11, J16, J24, J25: PJ301_GUI6; OG-PJ301_VARIATIONS_WQP_PJ_301M6
JTAG1: M05X2MINIJTAG; 2X5-1.27
LED4, LED5, LED6: WP115VEGW; LED-BICOLOR-THROUGHHOLE
Q1: 8MHz; HC49UP
Q3, Q4, Q5, Q6, Q7: MMBT3904; SOT23-BEC
R3, R4, R5, R6, R7, R8: 100; R0603
R96, R97, R98, R102, R107: 10k; R0603
R103, R106: 3.3k; R0603
R104, R105: 4.7k; R0603
R108, R109, R110: 100k; R0603
SW3, SW4: TL1100X
UC1: STM32F103CBT6; LQFP48

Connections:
+3V3: C22.1, C23.1, C36.1, JTAG1.1, UC1.1 (VBAT), UC1.24 (VDD_1), UC1.36 (VDD_2), UC1.48 (VDD_3); also elsewhere on the board
+3V3_A: C26.1, C28.1, C48.1, C50.1, IC9.1 (VDD), R96.2, R97.2, R98.2, UC1.9 (VDD_A); also elsewhere on the board
AREF_2.5: IC9.2 (VREF); also elsewhere on the board
ASYM_ADC: UC1.18 (PB0/ADC12_IN8/TIM3_CH3); also elsewhere on the board
ATTENUVERTER_ADC: UC1.12 (PA2/USART2_TX/ADC12_IN2/TIM2_CH3); also elsewhere on the board
BI: IC9.3 (OUTB); also elsewhere on the board
BOOT_FLASH: UC1.44 (BOOT0); also elsewhere on the board
CLOCK: Q6.C, R97.1, UC1.21 (PB10/I2C2_SCL/USART3_TX); also elsewhere on the board
CYCLE_SW: SW3.3 (S), SW3.4 (S1), UC1.10 (PA0_WKUP/USART2_CTS/ADC12_IN0/TIM2_CH1_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); also elsewhere on the board
DAC_MOSI: IC9.7 (DIN), UC1.28 (PB15/SPI2_MOSI/TIM1_CH3N); also elsewhere on the board
DAC_SCK: IC9.6 (SCLK), UC1.26 (PB13/SPI2_SCK/USART3_CTS/TIM1_CH1N); also elsewhere on the board
DAC_SS: IC9.5 (!SYNC), UC1.25 (PB12/SPI2_NSS/I2C2_SMBA/USART3_CK/TIM1_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); also elsewhere on the board
EOA_B: J24.P3 (3), Q4.C, R105.1, R106.2
EOA_OUT: R107.1, UC1.33 (PA12/USART1_RTS/CAN_TX/TIM1_ETR/USBDP); also elsewhere on the board
EOD_B: J25.P3 (3), Q3.C, R103.2, R104.1; also elsewhere on the board
EOD_OUT: R102.1, UC1.32 (PA11/USART1_CTS/CAN_RX/TIM1_CH4/USBDM); also elsewhere on the board
FM_ADC: UC1.14 (PA4/SPI1_NSS/USART2_CK/ADC12_IN4); also elsewhere on the board
FREEZE: Q5.C, R96.1, UC1.19 (PB1/ADC12_IN9/TIM3_CH4); also elsewhere on the board
GND: C10.1, C12.1, C22.2, C23.2, C26.2, C28.2, C36.2, C48.2, C50.2, IC9.8 (GND), J10.P1 (1), J11.P1 (1), J11.P2 (2), J16.P1 (1), J16.P2 (2), J24.P1 (1), J25.P1 (1), JTAG1.3, JTAG1.5, JTAG1.9, LED4.2 (C), LED5.2 (C), LED6.2 (C), Q3.E, Q4.E, Q5.E, Q6.E, Q7.E, R103.1, R106.1, SW3.1, SW3.2 (P1), SW4.1, SW4.2 (P1), UC1.8 (VSS_A), UC1.20 (PB2/BOOT1), UC1.23 (VSS_1), UC1.35 (VSS_2), UC1.47 (VSS_3); also elsewhere on the board
JTCK: JTAG1.4, UC1.37 (PA14/JTCK/SWCLK); also elsewhere on the board
JTDI: JTAG1.8, UC1.38 (PA15/JTDI); also elsewhere on the board
JTDO: JTAG1.6, UC1.39 (PB3/JTDO); also elsewhere on the board
JTMS: JTAG1.2, UC1.34 (PA13/JTMS/SWDIO); also elsewhere on the board
LEVEL_ADC: UC1.16 (PA6/SPI1_MISO/ADC12_IN6/TIM3_CH1); also elsewhere on the board
unnamed: C12.2, Q1.2, UC1.5 (PD0-OSC_IN)
unnamed: C10.2, Q1.1, UC1.6 (PD1-OSC_OUT)
unnamed: Q4.B, R107.2
unnamed: Q3.B, R102.2
unnamed: LED6.3 (RED), R3.2
unnamed: LED6.1 (GRN), R4.2
unnamed: LED5.3 (RED), R5.2
unnamed: LED5.1 (GRN), R6.2
unnamed: LED4.3 (RED), R7.2
unnamed: LED4.1 (GRN), R8.2
unnamed: R3.1, UC1.46 (PB9/TIM4_CH4)
unnamed: R4.1, UC1.45 (PB8/TIM4_CH3)
unnamed: R5.1, UC1.43 (PB7/I2C1_SDA/TIM4_CH2)
unnamed: R6.1, UC1.42 (PB6/I2C1_SCL/TIM4_CH1)
unnamed: R7.1, UC1.41 (PB5/I2C1_SMBA)
unnamed: R8.1, UC1.40 (PB4/NJTRST)
unnamed: J10.P3 (3), R110.1
unnamed: Q7.B, R110.2
unnamed: J16.P3 (3), R108.1
unnamed: Q5.B, R108.2
unnamed: J11.P3 (3), R109.1
unnamed: Q6.B, R109.2
PROC_ADC: UC1.17 (PA7/SPI1_MOSI/ADC12_IN7/TIM3_CH2); also elsewhere on the board
RANGE_SW: SW4.3 (S), SW4.4 (S1), UC1.11 (PA1/USART2_RTS/ADC12_IN1/TIM2_CH2); also elsewhere on the board
RESET: JTAG1.10, UC1.7 (NRST); also elsewhere on the board
RX: UC1.31 (PA10/USART1_RX/TIM1_CH3); also elsewhere on the board
SHAPE_ADC: UC1.15 (PA5/SPI1_SCK/ADC12_IN5); also elsewhere on the board
START: Q7.C, R98.1, UC1.22 (PB11/I2C2_SDA/USART3_RX); also elsewhere on the board
TRIGGIN_B: J10.P2 (2); also elsewhere on the board
TX: UC1.30 (PA9/USART1_TX/TIM1_CH2); also elsewhere on the board
UNI: IC9.4 (OUTA); also elsewhere on the board
VCC: R104.2, R105.2; also elsewhere on the board
VOCT_ADC: UC1.13 (PA3/USART2_RX/ADC12_IN3/TIM2_CH4); also elsewhere on the board

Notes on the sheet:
cc-by-sa
Émilie Gillet
ol.gillet@gmail.com
Digital section
mini JTAG
Mangu Díaz 2018

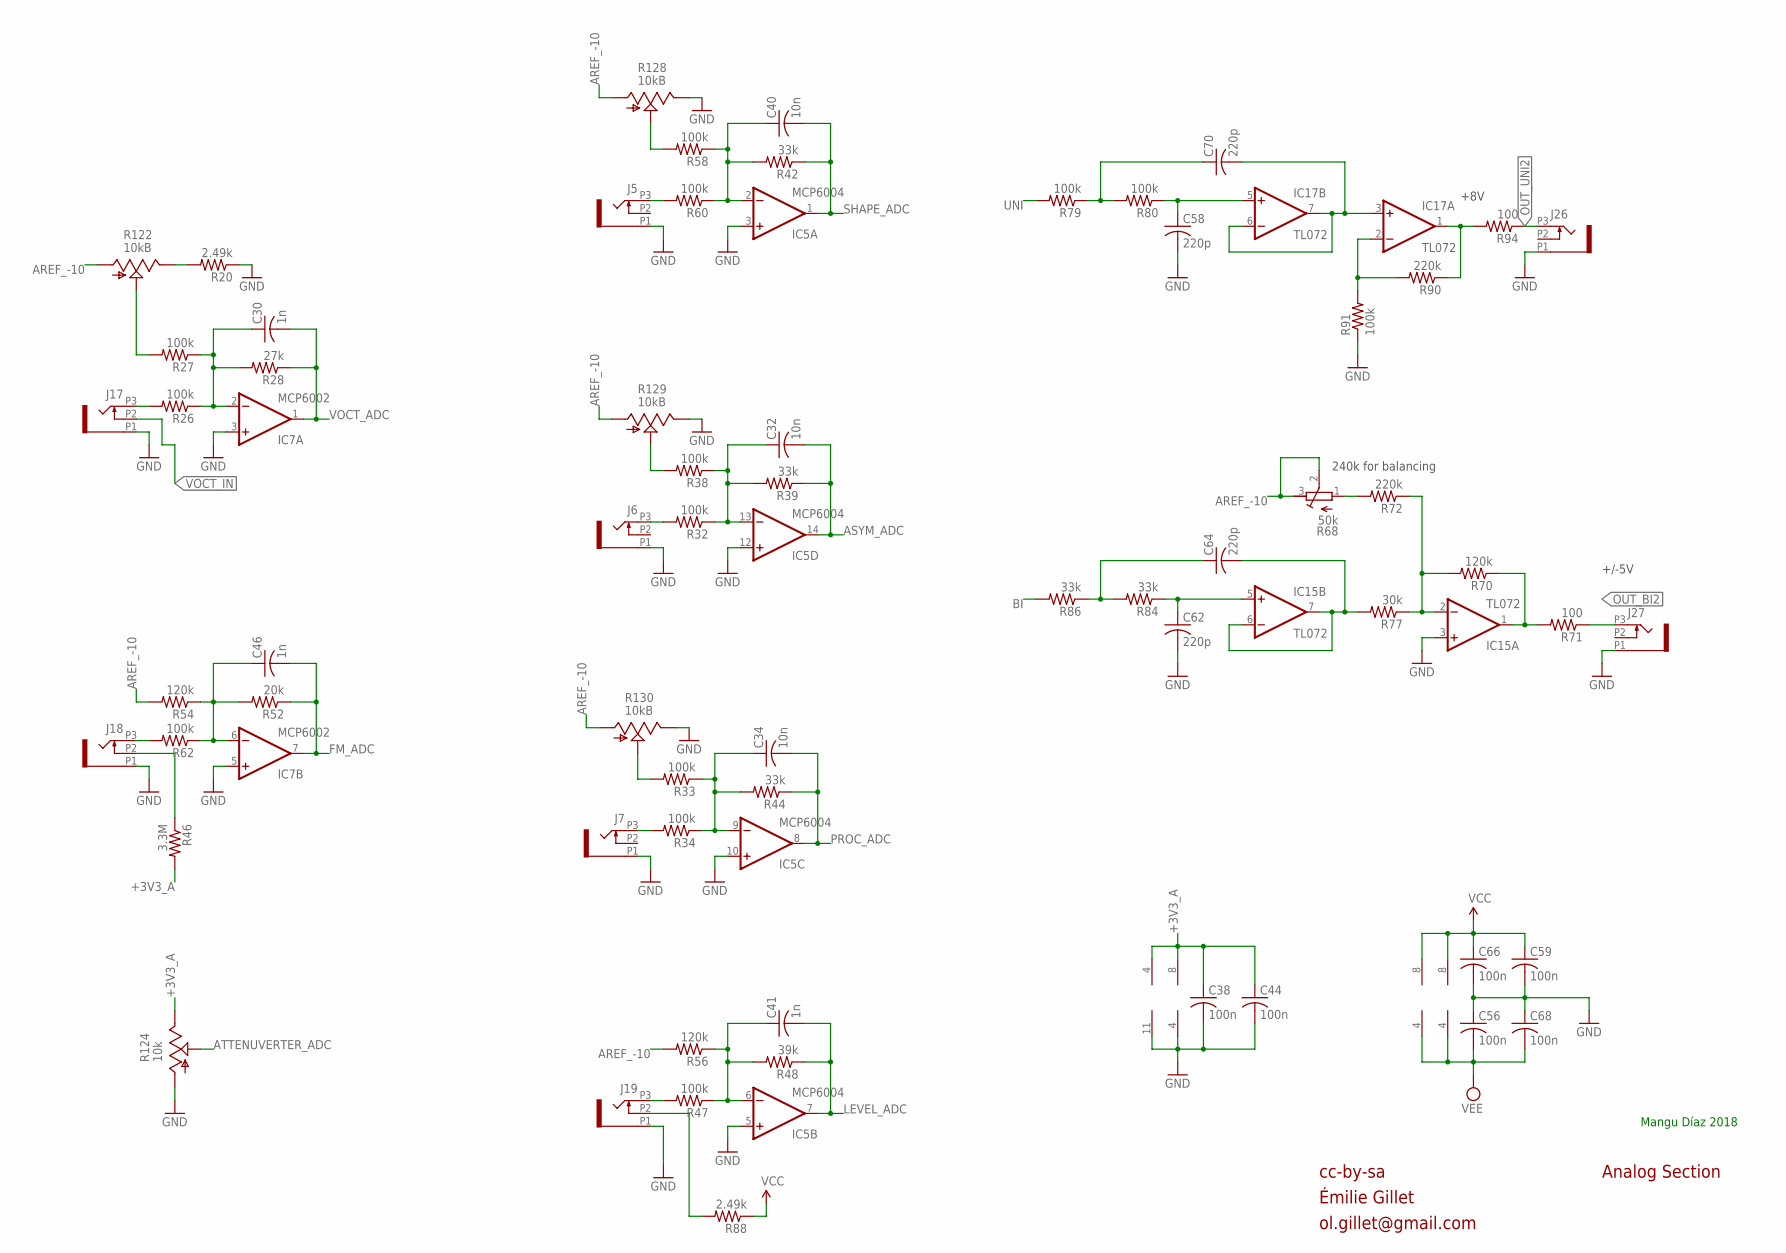
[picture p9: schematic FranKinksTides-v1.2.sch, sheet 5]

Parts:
C30, C41, C46: 1n; C0603
C32, C34, C40: 10n; C0603
C38, C44, C56, C59, C66, C68: 100n; C0603
C58, C62, C64, C70: 220p; C0603
IC5: MCP6004; TSSOP14
IC7: MCP6002; SO08
IC15, IC17: TL072; TSSOP-8
J5, J6, J7, J17, J18, J19, J26, J27: PJ301_GUI6; OG-PJ301_VARIATIONS_WQP_PJ_301M6
R20: 2.49k; R0603
R26, R27, R32, R33, R34, R38, R47, R58, R60, R62, R79, R80, R91: 100k; R0603
R28: 27k; R0603
R39, R42, R44, R84, R86: 33k; R0603
R46: 3.3M; R0603
R48: 39k; R0603
R52: 20k; R0603
R54, R56, R70: 120k; R0603
R68: 50k; RTRIM3296W
R71, R94: 100; R0603
R72, R90: 220k; R0603
R77: 30k; R0603
R88: 2.49k; R0805
R122: 10kB; ALPS_POT_VERTICAL_PS
R124: 10k; TALLTRIMMER
R128, R129, R130: 10kB; TALLTRIMMER

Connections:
+3V3_A: C38.1, C44.1, IC5.4 (V+), IC7.8 (V+), R46.2, R124.P$1 (E); also elsewhere on the board
AREF_-10: R54.2, R56.2, R68.2 (S), R68.3 (E), R122.P$3 (A), R128.P$3 (A), R129.P$3 (A), R130.P$3 (A); also elsewhere on the board
ASYM_ADC: C32.2, IC5.14 (OUT), R39.1; also elsewhere on the board
ATTENUVERTER_ADC: R124.P$2 (S); also elsewhere on the board
BI: R86.2; also elsewhere on the board
BI_OUT1: IC15.1 (OUT), R70.1, R71.2
FM_ADC: C46.2, IC7.7 (OUT), R52.1; also elsewhere on the board
F_CV1: IC15.2 (-IN), R70.2, R72.1, R77.1
GND: C38.2, C44.2, C56.1, C58.2, C59.2, C62.2, C66.2, C68.1, IC5.3 (+IN), IC5.5 (+IN), IC5.10 (+IN), IC5.11 (V-), IC5.12 (+IN), IC7.3 (+IN), IC7.4 (V-), IC7.5 (+IN), IC15.3 (+IN), J5.P1 (1), J6.P1 (1), J7.P1 (1), J17.P1 (1), J18.P1 (1), J19.P1 (1), J26.P1 (1), J27.P1 (1), R20.1, R91.1, R124.P$3 (A), R128.P$1 (E), R129.P$1 (E), R130.P$1 (E); also elsewhere on the board
LEVEL_ADC: C41.2, IC5.7 (OUT), R48.1; also elsewhere on the board
unnamed: J5.P3 (3), R60.2
unnamed: C40.1, IC5.2 (-IN), R42.2, R58.1, R60.1
unnamed: R58.2, R128.P$2 (S)
unnamed: J6.P3 (3), R32.2
unnamed: C32.1, IC5.13 (-IN), R32.1, R38.1, R39.2
unnamed: R38.2, R129.P$2 (S)
unnamed: J7.P3 (3), R34.2
unnamed: C34.1, IC5.9 (-IN), R33.1, R34.1, R44.2
unnamed: R33.2, R130.P$2 (S)
unnamed: J19.P3 (3), R47.2
unnamed: C41.1, IC5.6 (-IN), R47.1, R48.2, R56.1
unnamed: J17.P3 (3), R26.2
unnamed: C30.1, IC7.2 (-IN), R26.1, R27.1, R28.2
unnamed: R27.2, R122.P$2 (S)
unnamed: R20.2, R122.P$1 (E)
unnamed: J18.P3 (3), R62.2
unnamed: C46.1, IC7.6 (-IN), R52.2, R54.1, R62.1
unnamed: C70.2, IC17.3 (+IN), IC17.6 (-IN), IC17.7 (OUT)
unnamed: C58.1, IC17.5 (+IN), R80.1
unnamed: C70.1, R79.1, R80.2
unnamed: IC17.2 (-IN), R90.2, R91.2
unnamed: C64.2, IC15.6 (-IN), IC15.7 (OUT), R77.2
unnamed: C62.1, IC15.5 (+IN), R84.1
unnamed: C64.1, R84.2, R86.1
unnamed: J18.P2 (2), R46.1
unnamed: IC17.1 (OUT), R90.1, R94.2
unnamed: R68.1 (A), R72.2
unnamed: J19.P2 (2), R88.2
OUT_BI2: J27.P3 (3), R71.1; also elsewhere on the board
OUT_UNI2: J26.P3 (3), R94.1; also elsewhere on the board
PROC_ADC: C34.2, IC5.8 (OUT), R44.1; also elsewhere on the board
SHAPE_ADC: C40.2, IC5.1 (OUT), R42.1; also elsewhere on the board
UNI: R79.2; also elsewhere on the board
VCC: C59.1, C66.1, IC15.8 (V+), IC17.8 (V+), R88.1; also elsewhere on the board
VEE: C56.2, C68.2, IC15.4 (V-), IC17.4 (V-); also elsewhere on the board
VOCT_ADC: C30.2, IC7.1 (OUT), R28.1; also elsewhere on the board
VOCT_IN: J17.P2 (2); also elsewhere on the board

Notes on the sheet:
cc-by-sa
Émilie Gillet
ol.gillet@gmail.com
Analog Section
+8V
+/-5V
240k for balancing
Mangu Díaz 2018

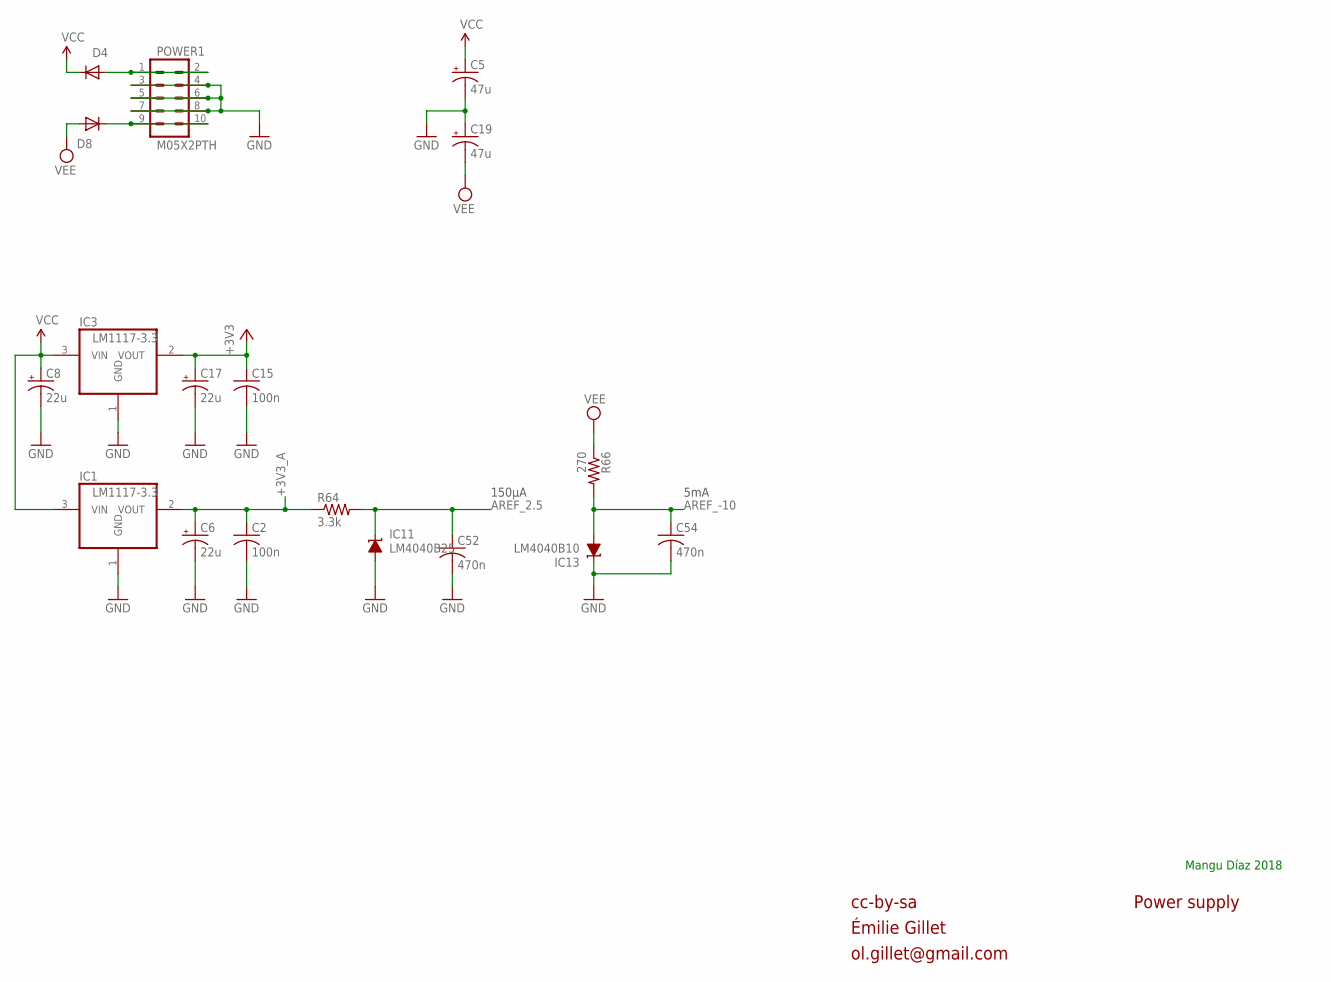
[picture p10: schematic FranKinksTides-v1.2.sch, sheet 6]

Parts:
C2, C15: 100n; C0603
C5, C19: 47u; PANASONIC_D
C6, C8, C17: 22u; PANASONIC_C
C52, C54: 470n; C0603
D4, D8: 1N5819HW; SOD123
IC1, IC3: LM1117-3.3; SOT223
IC11: LM4040B25; DBZ_R-PDSO-G3
IC13: LM4040B10; DBZ_R-PDSO-G3
POWER1: M05X2PTH; AVR_ICSP
R64: 3.3k; R0603
R66: 270; R0603

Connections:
+3V3: C15.1, C17.+, IC3.2 (VOUT); also elsewhere on the board
+3V3_A: C2.1, C6.+, IC1.2 (VOUT), R64.1; also elsewhere on the board
AREF_2.5: C52.1, IC11.1 (C), R64.2; also elsewhere on the board
AREF_-10: C54.1, IC13.2 (A), R66.2; also elsewhere on the board
GND: C2.2, C5.-, C6.-, C8.-, C15.2, C17.-, C19.+, C52.2, C54.2, IC1.1 (GND), IC3.1 (GND), IC11.2 (A), IC13.1 (C), POWER1.3, POWER1.4, POWER1.5, POWER1.6, POWER1.7, POWER1.8; also elsewhere on the board
unnamed: D4.A, POWER1.1, POWER1.2
unnamed: D8.C, POWER1.9, POWER1.10
VCC: C5.+, C8.+, D4.C, IC1.3 (VIN), IC3.3 (VIN); also elsewhere on the board
VEE: C19.-, D8.A, R66.1; also elsewhere on the board

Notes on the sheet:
cc-by-sa
Émilie Gillet
ol.gillet@gmail.com
Power supply
5mA
150µA
Mangu Díaz 2018

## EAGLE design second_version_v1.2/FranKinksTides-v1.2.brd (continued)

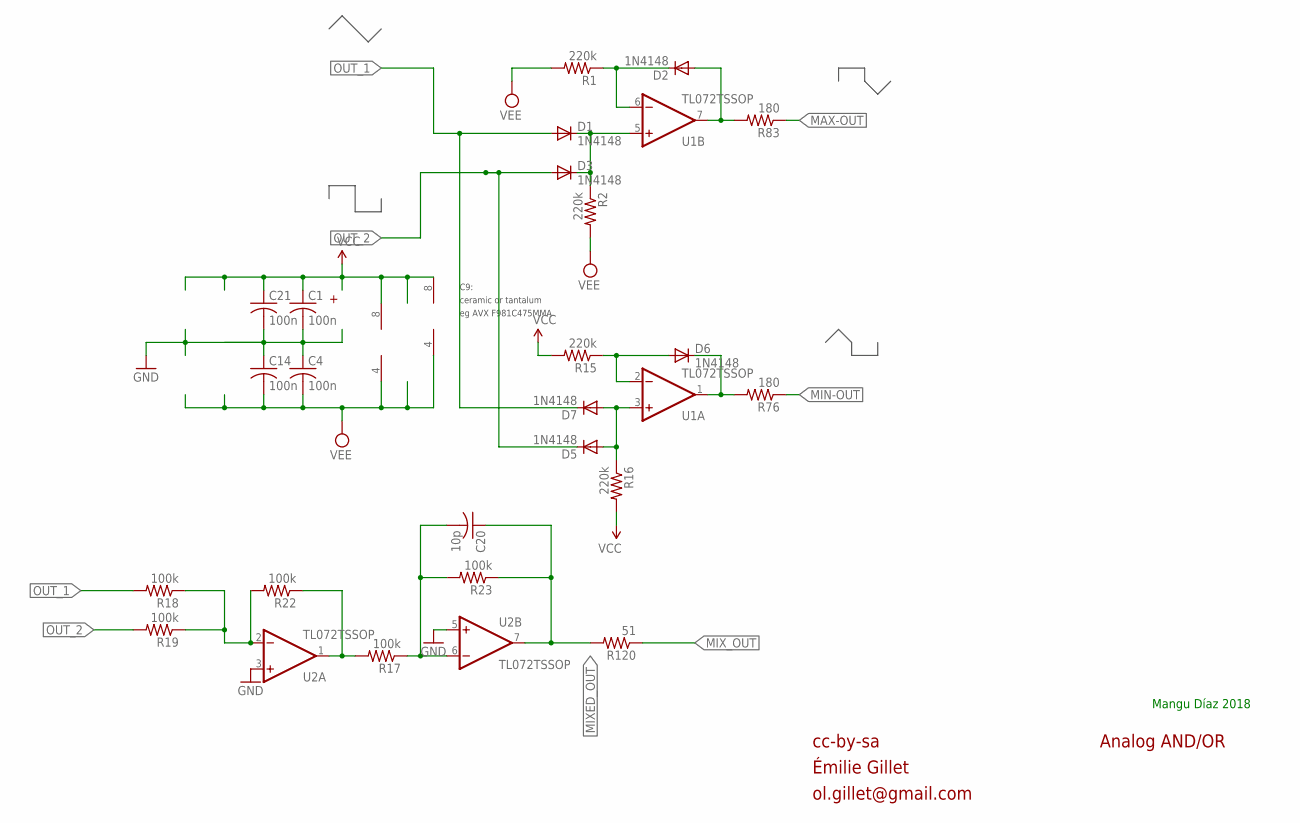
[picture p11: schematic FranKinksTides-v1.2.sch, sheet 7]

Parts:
C1, C4, C14, C21: 100n; C0603
C20: 10p; C0603
D1, D2, D3, D5, D6, D7: 1N4148; SOD123
R1, R2, R15, R16: 220k; R0603
R17, R18, R19, R22, R23: 100k; R0603
R76, R83: 180; R0603
R120: 51; R0603
U1, U2: TL072TSSOP; TSSOP-8

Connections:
GND: C1.2, C4.1, C14.1, C21.2, U2.3 (+IN), U2.5 (+IN); also elsewhere on the board
MAX-OUT: R83.1; also elsewhere on the board
MIN-OUT: R76.1; also elsewhere on the board
MIXED_OUT: C20.1, R23.1, R120.2, U2.7 (OUT)
MIX_OUT: R120.1; also elsewhere on the board
unnamed: R17.2, R22.1, U2.1 (OUT)
unnamed: D1.C, D3.C, R2.1, U1.5 (+IN)
unnamed: D2.A, R83.2, U1.7 (OUT)
unnamed: C20.2, R17.1, R23.2, U2.6 (-IN)
unnamed: R18.1, R19.1, R22.2, U2.2 (-IN)
unnamed: D2.C, R1.1, U1.6 (-IN)
unnamed: D5.A, D7.A, R16.1, U1.3 (+IN)
unnamed: D6.C, R76.2, U1.1 (OUT)
unnamed: D6.A, R15.1, U1.2 (-IN)
OUT_1: D1.A, D7.C, R18.2; also elsewhere on the board
OUT_2: D3.A, D5.C, R19.2; also elsewhere on the board
VCC: C1.1, C21.1, R15.2, R16.2, U1.8 (V+), U2.8 (V+); also elsewhere on the board
VEE: C4.2, C14.2, R1.2, R2.2, U1.4 (V-), U2.4 (V-); also elsewhere on the board

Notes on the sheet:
cc-by-sa
Émilie Gillet
ol.gillet@gmail.com
Analog AND/OR
eg AVX F981C475MMA
ceramic or tantalum
C9:
Mangu Díaz 2018

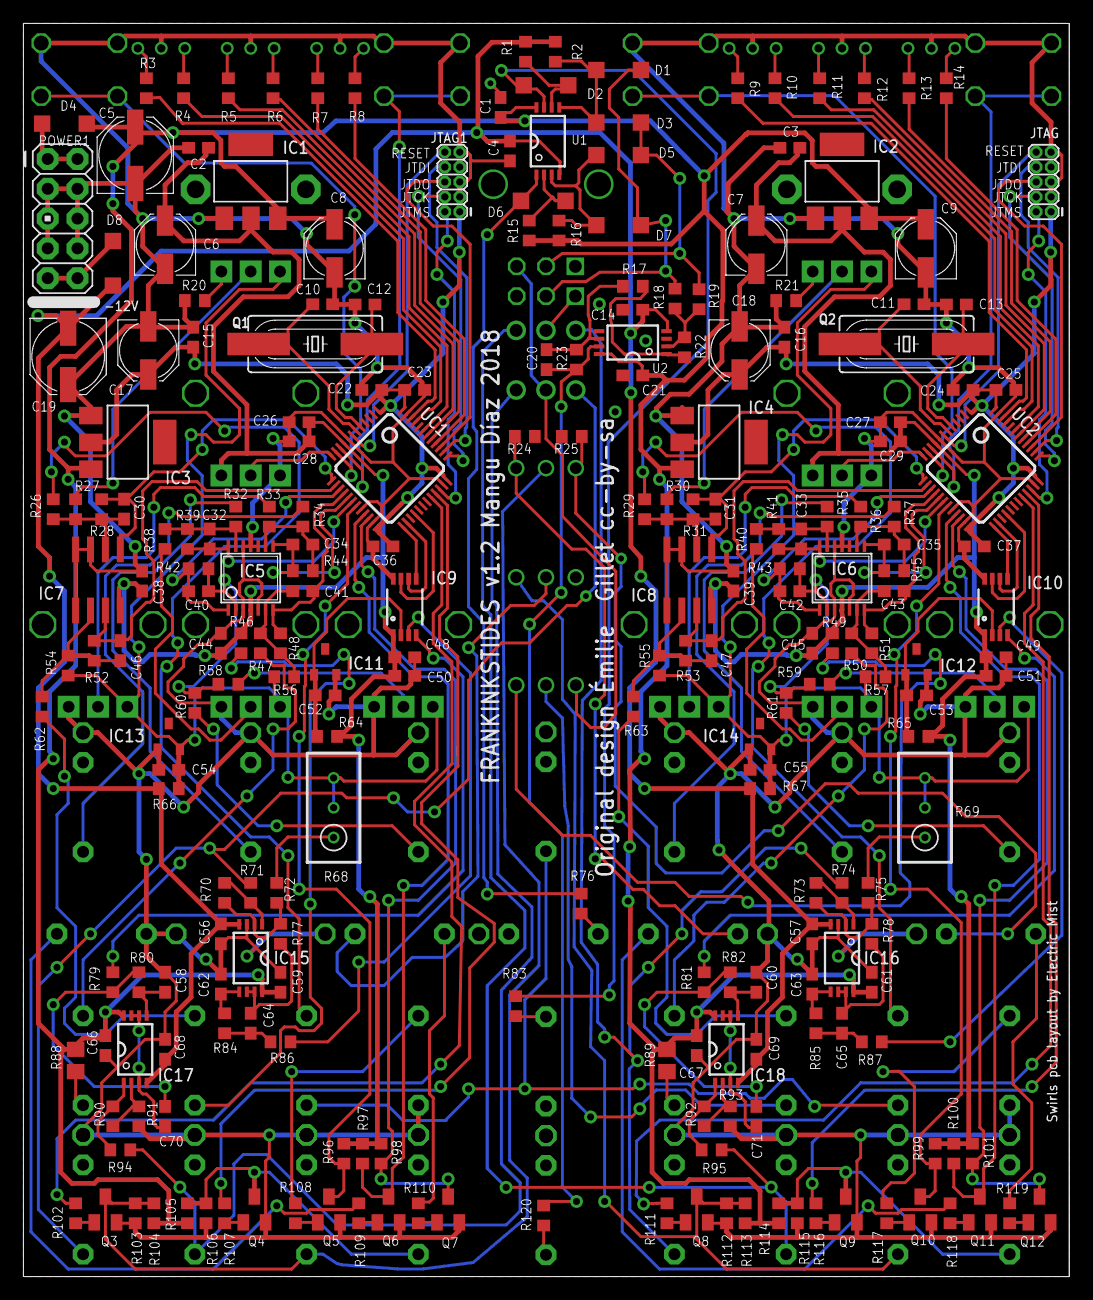
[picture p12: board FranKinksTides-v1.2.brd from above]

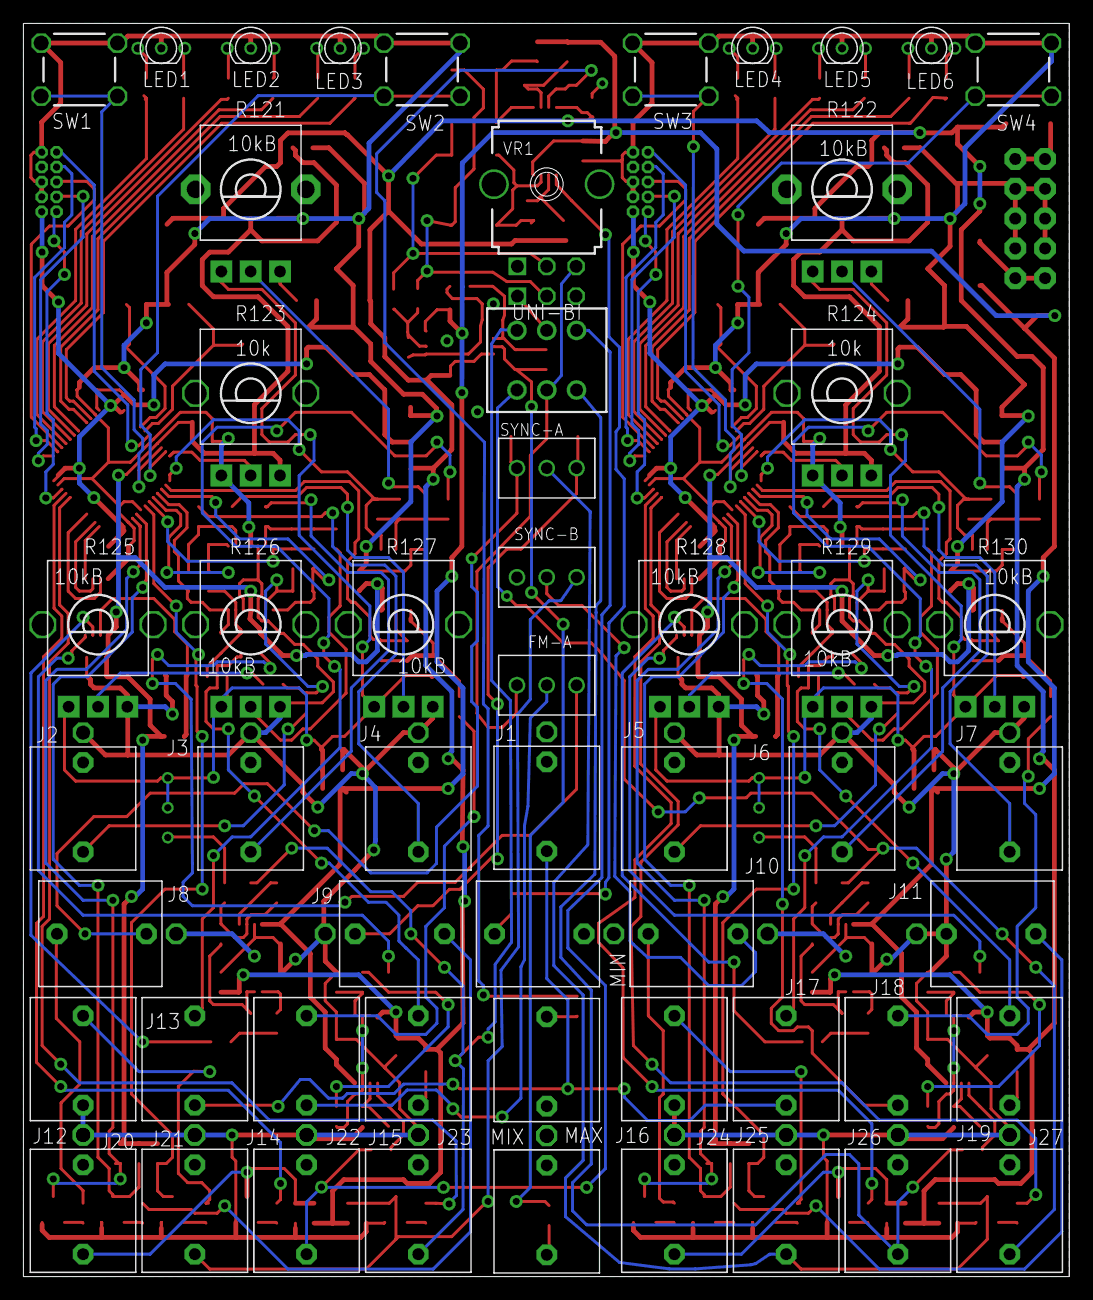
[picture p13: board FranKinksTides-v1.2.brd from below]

Board: 2 copper layers, 89.1 x 106.8 mm, 291 parts (55 on the bottom side), 170 nets.

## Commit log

2020-06-14 first version added
    [FranKinksTides.GBL, FranKinksTides.GBO, FranKinksTides.GBP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]
2020-06-14 files uploaded
    [FranKinksTides v1.2 B.O.M. - FranKinksTides 1.2.csv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]

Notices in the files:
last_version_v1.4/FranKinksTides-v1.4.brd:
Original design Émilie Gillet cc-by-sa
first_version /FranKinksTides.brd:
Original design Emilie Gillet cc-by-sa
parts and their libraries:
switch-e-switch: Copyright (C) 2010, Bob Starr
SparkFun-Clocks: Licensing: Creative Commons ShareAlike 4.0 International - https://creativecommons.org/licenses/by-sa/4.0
